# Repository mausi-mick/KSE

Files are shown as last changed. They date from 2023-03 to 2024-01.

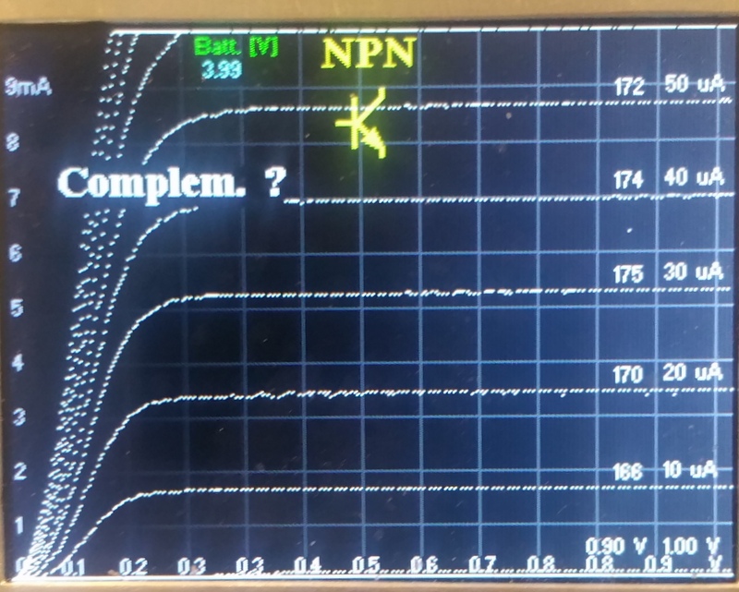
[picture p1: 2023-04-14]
SX1308_SDB628_Modul.jpg

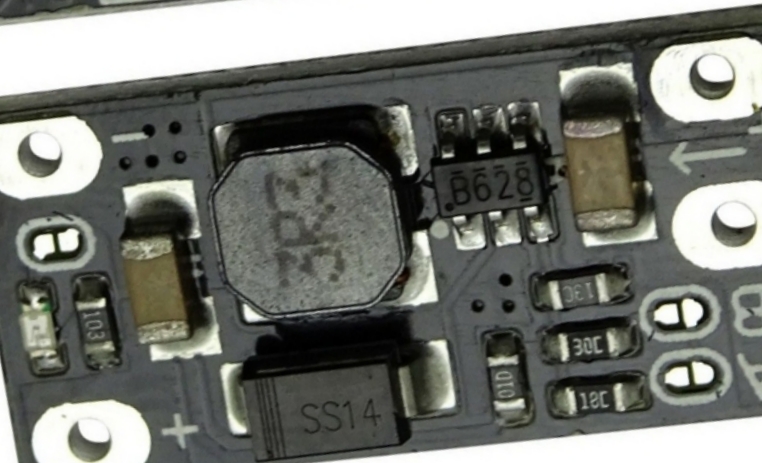
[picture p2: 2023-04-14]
SDB628.jpeg

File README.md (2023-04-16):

   Kleiner , feiner  Kennlinienschreiber

Wozu braucht man einen Kennlinienschreiber ?

Reicht nicht ein Transistortester oder ein Voltmeter?
Für einen ersten Check ist ein Transistortester sehr hilfreich, zumal er auch den Typ des Transistors  und die Pin-Belegung ermitteln und anzeigen kann.

Aber die Ausgabewerte beziehen sich dabei nur auf einen Arbeitspunkt (Kollektorstrom).
Für den Schaltungsentwickler ist es aber oft wichtig, wie sich das Bauteil an verschiedenen
Arbeitspunkten – z.B. Basisströmen – verhält.

Worin unterscheidet sich der hier vorgestellte Kennlineinschreiber von anderen?

    • kompakter Aufbau:                                                                                                 Abmessungen: 8x9x6cm (lxbxh),  Gewicht: < 500 g (inkl. 18650 Lio-Akku).
    • unabhängig von externer Stromversorgung (Akku Betrieb,mit einer 18650 Zelle)
    • ausgelegt für bipolar Transistoren/Dioden, MosFets, J-Fets(incl. Depl.Mode MosFets).
    • Kollektor/Emitterspannung < 12V , 0 ..150mA  optimal für Kleinleistungstransistoren
    • Basisstrom von ca 5µA ... 1000µA mit präziser Konstant-Stromquelle, 
    • Gatespannung  100 mV ...12 V in 100 mV Schritten (änderbar), 
    • einstellbare Strombegrenzung (z.B. Dioden 5mA, 50mA,…)
    • relativ grosses Farbdisplay (3.2“)
    • einfache und schnelle Eingabe über Dreh-Encoder an Interrupt-Pins
    • hohe Genauigkeit und klare Kennlinien dank 12 bit ADC’s / DAC’s
    • diverse Skalen für x (U) und y-(I) Achse : detaillierte Darstellung interessanter Bereiche
    • Direkter Vergleich von Kennlinien (Typen gleicher Polarität oder Komplementärtyp)
    • Anzeige von typischen Werten wie Beta(Ib), V-Threshold,V-Pinch, Idss
    • Bluetooth Schnittstelle (BLE 4.0) für Datentransfer zum PC bzw. Smartphone/ Tablet
    • Datentransfer über USB zur Darstellung der Kurven auf PC mit z.B. Processing.
    • Speichern der Eingabeparameter im internen EEPROM
    • geringer Stromverbrauch: Uce (15V) erst bei Messvorgang zugeschaltet. 
    • Zusatzfunktion: einstellbare  Konstantspannungsquelle 1 mV  bis 12, 00V,> 10 mA
    • Zusatzfunktion: einstellbare Konstanstromquelle von 1µA bis 4000 µA
    • Zusatzfunktion: Treppenstufengenerator für niedrige Frequenzen +4V, ...0V (...-4V) 
    • untergebracht auf 5 Platinen (Kicad) einlagig 
    • relativ niedrige Bauteilkosten

Dieser Kennlinienschreiber basiert auf dem sehr interessanten und gut dokumentierten Projekt von Peter Balch : Transistor Curve Tracer [1], aus dem auch u.a. die Grafik-library leicht modifiziert übernommen wurde.

Ich habe mich dann aber doch ziemlich  - auch vom Konzept her - weit davon entfernt, um eine bessere und rauschärmere Darstellung hinzubekommen mit einem deutlich erweiterten Messbereich ,einer einfachen Bedienung und erweiterter Funktionalität, was sich leider auch im Preis niederschlägt. 
Ich habe die bisherige Bedienung über das Touchpanel eliminiert und mache die Programmsteuerung und Parameteränderungen über zwei Drehencoder, die an den beiden ext. Interrupt-Pins des NANO hängen und so eine schnelle Reaktion ermöglichen. Die Eingabe ist hiermit – gerade bei dem kleinen Display und den vielen Parameterwerten – wesentlich angenehmer und schneller als per Touch. 

Der Nachbau ist wegen einiger SMDs  und der Verdrahtung einiger Platinen  komplexer und daher nicht unbedingt für „Anfänger“ geeignet. Bei einigen Spezial-ICs ist/war auch mit erheblichen Beschaffungszeiten (in Deutschland) zu rechnen.

Basis ist ein Arduino-NANO(Clone), am besten mit vorinstalliertem Opti-Boot Loader [2,3,4], da man dort 1.5 kB mehr freien Flash-Speicher hat, ansonsten hat man nur einige 100 Byte Flash frei.

Anmerkung:
 ATMega328 Board mit vorinstalliertem Opti-Boot-Loader: 
 z.B. Arduino-UNO, Adafruit Metro Mini 328,  oder ein Board mit mehr Flash und Port-Pins (für Erweiterungen): ATMega2560 ).

Anmerkung:
Auch das UNO-Board oder Adafruit Metro-Mini sind hier verwendbar, da ich die zusätzlichen rein analogen Pins des NANO (A6,A7) nicht benutze.

Das Adafruit-Board Metro Mini 328 hat neben der besseren Anordnung der Pins (alle digit.Pins und somit auch Pin13 (SPI-SCK)  auf einer Seite) auch die Möglichkeit, durch eine Lötbrücke die Pegel auf 3.3V zu setzen, sodass man für das Display und das HM-10 BLE-Modul keine Spannungsteiler zur Pegelanpassung benötigt.

Der Mikroprozessor steuert zwei 12bit-DACs (im MCP4822 SPI) für die Uce Versorgung , ausserdem für die Basis/Gate-Ansteuerung einen 12 bit DAC (MCP4725-I2C) an, der über einen DC/DC-Wandler (5 V → 30V) und für den I2C Bus über einen ADUM1250/51 isoliert betrieben wird.  

Dieser total isolierte DAC (Bereich von 1µA bis 4mA, 1µA Schritte, hier nur von 5µA bis 1200µA genutzt für die bipol. Transistoren genutzt) erzeugt den Basisstrom bzw. die Gate-Spannung in der – zum Bauteil / „device“ - passenden Polarität über eine Präzisionskonstantstromquelle.
 
Zugeschaltet wird der Basisstrom (bzw. die Gatespannung)  über elekronische Schalter („Photomos-Relais“) mit niedrigem On-Widerstand und Leckstrom (z.B. TLP222A ).

Neben diesen DACs wird auch ein 12-bit ADC (MCP3402 SPI) zur Messung der Collector-EmitterSpannung und zur am Messwiderstand RS (50 Ohm) abfallenden Spannung (zur Ermittlung des Collector-Stroms) verwandt. Er dient auch zur Überwachung der Akku-Spannung.
Momentan werden nur 3 von den 4 Eingängen des ADC’s genutzt.

Ausserdem versorgt der NANO das bis zu 3.2 Zoll grosse Farb-Display (ILI9341) (an SPI-Bus).

Probleme gab es mit den 4 SPI-Devices wegen der unterschiedlichen Geschwindigkeit, da das Display mit 8 MHz läuft, die DAC’s mit 3.6 MHz und der ADC aber nur mit 2 MHz                      (und der Touch noch langsamer, wird aber in dieser Version nicht genutzt).

Als realisierbare / nicht ganz perfekte Lösung speichere ich maximal 320-Messwerte pro eingestelltem Basisstrom in einer Tabelle mit SPI-Speed 2 MHz ab.
Anschliessend erhöhe ich die SPI-Speed auf 8MHz für das Display und
 gebe die Tabellenwerte auf dem Display aus, um dann wieder – mit reduzierter SPI-Speed - die nächsten 320 Messwerte zum nächsten Basisstrom zu speichern.

Die Spannung Uc wird über die beiden DACs des MCP4822 erzeugt, wobei DAC-B nur
die Werte (0V, 2V,4V ...10V) am Opamp TCA0372 ausgibt,
DAC-A erzeugt die Zwischenwerte von 0.0mV, 0.5mV, 1.0mV.,..2000mV.
Sie werden dann zu den aus DC-B erzeugten Werten addiert (zwei invertierende Verstärker hintereinandergeschaltet) , sodass insgesamt der Bereich von
0V bis 12V in 0.5mV – Schritten mit sehr guter Linearität erzeugt werden kann.
Diese Auflösung ist zwar etwas übertrieben, bei kleinen Spannungswerten (z.B. Kennlinie von Shottky-Dioden oder im Anfangsbereich der Kurven von bipolar bzw. Feldeffekttransistoren) bringt das aber was, auch wird durch eine Art „Oversampling“ der Mittelwert der Messungen zum gleichen x_Wert gebildet

Der Summierverstärker TCA0372 mit Verstärkung +1 für DAC_A und Verstärkung +10 für DAC_B ist in Abbildung 1 skizziert.
Da der TCA0372 kein Rail-to Rail Vertärker ist, benötigt er eine negative Hilfsspannung: 
 aus den +15V wird mithilfe eines kleinen Spannungswandlers (LMO78-5-.5 )  -5V erzeugt. 
Damit erhält man auch in Nullpunktsnähe saubere Kurven, gerade die 1, 2, 3V Skalen profitieren davon.

Stromversorgung

Versorgt wird der Kennlinienschreiber aus einer einzelnen Lion-Akku-Zelle (18650).
Es werden zwei Spannungen benötigt:
   5V für  Adafruit Metro mini bzw. 7,5V Arduino NANO) , an der auch das Diplay und die KonstantStromquelle hängen, und ca.
 15V zur Versorgung des TCA0372-Verstärkerboards (Uce).

Die zuerst untersuchte Lösung mit zwei MT3608 Modulen funktionierte stabil nur für die 15V Versorgung, bei der Microprocessorversorgung brach die Spannung bereits bei einer Akkuspannung von 3.9V ein.

Die Qualität der MT3608-Module  – neben der riskanten Inbetriebnahme (siehe unten) – ist aber sehr unterschiedlich, sodass ich auch eher andere Module verwenden würde.
Die ICs MT3608, SDB628 und SX1308 scheinen – auch vom Datenblatt – identisch zu sein.
Aber die Module haben unterschiedliches Layout und wohl auch unterschiedliche Bestückung.

Die Kondensatoren C1 C2 sollten 22µF haben, bei den von mir untersuchten Modulen lagen sie 
unter 10 µF.

Es funktioniert sehr gut mit einem kleinen SX1308-Modul, bei dem bei mir aber ein SDB628 StepUp-Wandler IC aufgelötet war. 

Das Modul ist ähnlich wie das MT3608-Modul aufgebaut, aber
niederohmiger: 
10 k anstelle 100k Trimmer und 200 Ohm gegen Masse anstelle 2.2k. [9]

Es ist bei 15V mit mehr als 150mA belastbar und funktioniert bereits ab ca 2.7 V.
Es ist auch für die 5V / 7,5V Vesrorgung sehr gut geeignet.

Für die 5 bzw. 7.5V verwende ich momentan ein kleines Modul mit festen Spannungswerten  (5V,8V,9V,12V). Es ist wohl ein SDB628 verbaut ( identisch mit MT3608 / SX1308?)  das Modul funktioniert sogar  bis unter 3V Eingansspannung. [10]

Anmerkung MT3608:
Etwas kritisch ist die Einstellung/Inbetriebnahme, da der Schleifer des 10-Gang-Trimmers direkt mit dem FB (Feedback-Pin 3)  verbunden ist und - am oberen Anschlag  -  die Ausgansspannung direkt mit FB  verbunden ist, der wohl nur 0.6V ? verträgt.
Man sollte also vor Anlegen der Eingansspannung den Regler mit ein einigen Umdrehungen aus der oberenAnschlagsposition bringen (und zwar nach höheren Ausgansspannungswerten , d.h. nach links drehen   chinesische Logik ??)   [5,6],

Um Energie zu sparen, wird die 15V Versorgung erst aktiviert, wenn die Kurven aufbereitet werden.
Die 7.5V / 5V  stehen nach Einschalten für das Microprocessor Board gleich zur Verfügung, an dem u.a.  das Display und die Konstanstromquelle hängen, die aber weniger als 1W benötigt.

Beim Einschalten sind die Ströme - auch wegen der Kondensatoren - deutlich höher.

Das Adafruit Board braucht wegen eines besseren LD-Reglers , auch reichen hier 5V am  herausgeführten USB-Eingang.
9],[10],[11]

Testen von Bauteilen

Nach diesem technischen Überblick mal etrwas mehr zum Test-Ablauf:

Nach dem Einschalten erscheint auf dem Display der Startbildschirm , auf dem an der linken Seite nur drei grosse Icons  aufleuchten mit Auswahlfeldern (Buttons) für:
    •  bipolar Transistoren (inclusive Dioden)
    •  Mosfets
    •  Junction-Fets (incl. n-Depletion-Mode-Mosfets)
      
die über einen Drehencoder angesteuert werden.
Die Aktivierung einer Schaltfläche erfolgt durch Drehen des 2. Encoders.
Daraufhin werden im oberen Bereich zwei Schaltflächen („P“ bzw „N“) zum Starten des Messvorgangs angezeigt, vorher sollte man aber die unterhalb in zwei Spalten dargestellten Parameter begutachten  und eventuell modifizieren.
Im mittleren Display Bereich an der linken Seite  die Parameter: 

    •  min:   minimaler Wert (Basisstrom bzw. Gatespannung), mit dem der Messvorgang gestartet werden soll
    •  incr: Schrittweite, mit der Basisstrom bzw. Gatespannung erhöht werden soll
    •  max:  maximal datzustellende  Basisstrom bzw. Gatespannungs-Kurve

Die Basisströme werden in µA eingetragen, die Gatespannung in 100mV Schritten.
 Von einer Diode wird dann ausgegangen, wenn bei  „bipolar“ das Feld  incr: auf 0 gesetzt wird.

Am rechten Rand des Displays werden folgende Parameter angezeigt:

    •   Bluet/CCS: Transfer der Daten mit BLE 4.0 an PC bzw Smartphone,  bzw.    Konstantspannungs-Konstantspannungs-Betrieb
    •   x-scale[V]:    Länge der x-Skala  ( 1V,  2V,  3V,  4V,  6V,  12V)
    •   y-scale[mA]  Höhe   der y-Skala ( 2 mA, 5 mA, 10 mA, 20 mA, 50 mA, 100 mA)
Anmerkung: 
 Feld Bluet/CCS = 0         Ausgabe der Kennliniendaten 
                            = 1        Ausgabe der Kennliniendaten auch über Bluetooth an Smartphone etc. 
                            = 2        Umschalten auf Konstantspannungsquellen-Betrieb
                            = 3        Umschalten auf  Konstantstromquellen-Betrieb   
                            = 4,5 ,6 Treppenstufengenerator. 
                            
Die Verwaltung der Parameter erfolgt ähnlich wie beim Startbildschirm beschrieben, zwischen den Feldern springt man durch Drehen des Encoders 2, Auswahl eines Paramters durch mit dem anderen Encoder, ändern der Parameter duch Encoder-Drehung, Speichern/Verlassen des Parameters durch den andren Encoder.

Ist man mit den Einstellungen zufrieden, startet man den Messvorgang / Kurven durch Positionieren mit dem  Encoder auf Feld „P“  (für p-Devices) bzw. “N“ (für n-Devices)  
Hier hat man eine geringe Wartezeit zum Aktivieren, in der man nochmals die Parameter prüfen sollte. In dieser Wartephase blinken die aktivierten Felder P  bzw N. Durch drehen des anderen Encoders startet man dann den Messvorgang.

Erst jetzt sieht man die ausgewählten Skalen und im oberen Bereich das ausgewählte Device inclusive Icon.

Die Kurven werden vom x-y-0-Punkt aufgebaut und zusätzliche Daten (wie z.B. beta/hfe beim npn/pnp und der Basisstrom/Gatespannung )  am Ende der Kurven eingetragen.

Am Ende der Messung bleibt der Bildschirm mit den dargestellten Kurve stehen und es erscheint links oben eine Anfrage / Aufforderung in zeitlichem Abstand :

    •   ob man die Messung beenden will  („Stop ?“)
    •   ob man die Messung fortsetzen will mit geänderten Parametern  („Param ?“)
    •   ob man das gerade dargestellte Bauteil mit einem Bauteil gleicher Polarität vergleichen will („Compare ?“) 
    •   ob man das gerade dargestellete Bauteil mit einem Bauteil anderer Polarität vergleichen will („Complem. ?“)  (komplementär-Typ z.B. antiparallele Diode)

Die Auswahl erfolgt wieder durch Encoderdrehung zu dem gerade angezeigten Aufforderung.

Anmerkung:

Will man z.B. die Kennlinien von einem n-Device mit einem p-Device vergleichen, ermittelt man zuerst normal die Kennlinien des n-Devices, tauscht das n gegen das p-Device in der Textool Messfassung und startet den Vergleich 
durch Auswahl des Feldes „Complementary“ mit dem Encoder .

Es werden die Kennlinien des p-Devices zusätzlich in einer anderen Farbe auf dem Display dargestellt („Komplementärtyp“).

Vergleich von Komponenten gleicher Polarität erfolgt entsprechend 
durch Auswahl des Feldes „Compare“.

   Speicherung geänderter Parameter-im internen EEPROM

Die festgelegten Parameter werden beim Start der Kurven im internen EEPROM hinterlegt , 
sodass man auch beim Einschalten des Geräts die letzt eingegebenen Parameter angezeigt bekommt. 

Im EEPROM sind dafür folgende Adressen belegt:

    •   0: Transistor-Typ  0: bipolar,
    •   1: Bluetooth : 1=on, 0=off
    •   2: x-Skala: 1,2,3,4,6,12
    •   3 y-Skala: 2,5,10,20,50,100 mA
    •   4: minimaler Basisstrom bipolar-Transistor
    •   6: maximaler Basisstrom bipolar-Transistor 
    •   8: increment Basisstrom bipolar-Transistor 
    • 10: minimale Stepweite für Eingabe  min: ( Feld 4 )
    • 12: minimale StepWeite für Eingabe max: ( Feld 6 )
    • 14: minimale StepWeite für Eingabe incr:: ( Feld 8 )

    •   20: Transistor-Typ  1:  Mosfet
    •   21: Bluetooth : 1=on, 0=off
    •   22: x-Skala: 1,2,3,4,6,12
    •   23 y-Skala: 2,5,10,20,50,100 mA
    •   24: minimaler Gatespannung Mosfet
    •   26: maximaler GatespannungMosfet 
    •   28: increment Gatespannung Mosfet 
    •   30: minimale Stepweite für Eingabe  min: ( Feld 24 )
    •   32: minimale StepWeite für Eingabe max: ( Feld 26 )
    •   34: minimale StepWeite für Eingabe incr:: ( Feld 28 )

    •   40: Transistor-Typ  2:  J-Fet 
    •   41: Bluetooth : 1=on, 0=off
    •   42: x-Skala: 1,2,3,4,6,12
    •   43 y-Skala: 2,5,10,20,50,100 mA
    •   44: minimaler  Gatespannung J-Fet
    •   46: maximaler Gatespannung-J-Fet 
    •   48: increment  Gatespannung J-Fet 
    •   50: minimale Stepweite für Eingabe  min: ( Feld 44 )
    •   52: minimale StepWeite für Eingabe max: ( Feld 46 )
    •   54: minimale StepWeite für Eingabe incr:: ( Feld 48 )

Ausserdem kann man den Bauteil-Namen (z.B. BC548C  oder auch andere Informationen) im internen EEProm ab Adresse 100/101 hinterlegen: 

    •   100: Länge des Textfeldes 
    •   101: Text 1. Byte
    •   102: Text 2. Byte
    •  ...
 das Textfeld wird im Display unterhalb der P / N Buttons angezeigt und ist über einen Encoder basierten kleinen Editor verwaltbar – maximal 11 Einträge.
: 
   
 Datentransfer  über Bluetooth (BLE 4.0)

In das Gerät ist ein HM-10 Module integriert mit BLE 4.0, es ist über .Wippschalter mit der seriellen Schniitstelle RX / TX und damit mit USB verbunden. 
Die Aktivierung des Transfers erfolgt im Auswahl-Menü rechts oben unterhalb „N“-Button.
Bluet./CCS:  1   (0 für  Blutetooth nicht aktiviert)
Folgende Werte werden mit Separator Linefeed (“\n“ ) übertragen:

    • X:  x Skala und nachflolgend 1,2,3,4,6 oder 12 die SpannungsEndwerte der x-Achse
    • Y:  y-Skala und nachfolgend 2,5,10,20,50,100 die StromEndwerte der y-Achse
    • P  bzw. N : die Polarität (npn/pnp,nMos,pMos,nJFet,pJFet)
    • T, M, F (D) : der Typ (Transistor(bipolar), Mosfet, jFet (Diode noch nicht real.)
    • C: Kurve pro Basisstrom bzw. Gatespannung     hier werden jetzt bis zu 320 Werte der y- Achse  - durch Komma getrennt  -  ausgegeben
    • Q: Ende der Kurve
    • B:  bzw. G : für Basisstrom bzw. Gatespannung
    • E : Error Fehlermeldung bei Überschreitung des maximalen Collector-Stroms
    • H : hfe/beta von bipolar-Transistoren in Abhängigkeit vom Basisstrom (am Ende der Kurve)
    • O: Ohm (bei j_Fet mit Skala 1V ermittelt bei Uds =0.5V)
    • D : Diodenstrom bei Ud in mA (Diode wird „erkannt“, wenn bei npn/pnp incr=0)
    • U : Diodenspannung Ud bei Idiode in mV (Fluss bzw. Sperrspannung bei Zener < 12V)
    • Z : Ende der Kurve

Anmerkung  Bei ausgeschaltetem HM-010 Modul (BLE 4.0) können in Stellung  Bluet./CCS = 1
obige Parameter über USB an den PC übertragen werden und z.B. mit TeraTerm überwacht werden.

Verwendung als präzise KonstantSpannungsquelle

Der Modus:  Konstantspannungsquelle wird mit  Bluet./CCS = 2  aktiviert :

hier kann man bei dem Parameter  min.incr und max:  den den Spannungswert
bis maximal 12 V angeben. 

Verwendung als präzise Konstantstromquelle

Der Modus:  Konstantstromquelle wird mit  Bluet./CCS = 3  aktiviert :

hier kann man bei dem Parameter  max:  den den Konstanstrom in µA (1...4000) angeben. 

Verwendung als Treppenstufengenerator

Der Modus:  Treppenstufengenerator wird mit  Bluet./CCS  >= 4  aktiviert :

    • 4:  nur Stromwerte steigen von min::  µA bis max:  µA mit Schrittweite incr: µA
    • 5:  Stromwerte steigen (wie bei   4: ) und fallen 
    • 6:  Stromwerte steigen und fallen wie bei 5 :  mit Umschaltung Strom in negative Richtung (Treppenkurven von  maximal +4V … 0   -4V )
Die Verweildauer pro Stufe in µs wird über die Parameter x-scale und y-scale festgelegt.

Die Frequenz ergibt sich aus der Verweildauer und der über die Parameter-
 min:,  incr:  max:  festgelegten Stufenanzahl.

   Erweiterungsmöglichkleiten / Ausblick

    • grösserer Spannungs- / Strombereich Uce/Ic
Für manche Anwendungen ist der Spannungsbereich (Uce <= 12V)-
 bzw. Strombereich ( <100mA ) nicht ausreichend.
  Ein Betrieb mit bis zu 24V (der DC/DC-Wandler liefert maximal 28V) ist ohne HW-Änderungen möglich, allerdings zu Lasten des Stromverbrauchs , da sollte man das Gerät auf Betrieb mit 2 oder mehr Lion-Zellen umbauen oder den NANO mit 3.3V/3.6V betreiben (Umbauanleitungen im Netz, ab 3.6 V sicherer Betrieb des ATMega328P mit 20 MHz ). Da geht dann der Stromverbrauch im standby drastisch runter und man spart sich die Pegelanpassung für das TFT-Display. Ich hab aber die SPI-Schnittstellen zu den DACs und ADCs (auf dem TC0372-Board) bei 3.6V nicht getestet.
  Ein höherer Strombereich ist kritischer, da dann u.a. auch der Schaltregler an seine Grenzen kommt und der TCA0372 gekühlt werden müsste.

    • grösserer Strom Konstantstromquelle / CCS
   bis ca 10 mA leicht durch Ersetzen des Messwiderstandes  (250 Ohm) der CCS auf z.B 100 Ohm.
   Oberhalb muss man wohl u.a. auch den DC/DC-Wandler (1W/30V) wechseln und das Platinenlayout und den Mosfet entsprechend anpassen.

    • Schnittstelle zum Transistortester( „TT“):

            automatische Erkennung des Bauteils inclusive Pin-Zuordnung. 
Das ist mit dem NANO mit der jetzt integrierten Funktionalität nicht möglich, da der Flashspeicher bereits zu 99% belegt ist. Man müsste dann auf einen anderen Microprozessor zurückgreifen, z.B. den ATMega2560, der dazu auch noch eine Menge Port-Pins zur Verfügung stellt. 
Ich hab das mal – in einer einfacheren Version – mit einem NANO (+ Portexpander MCP23017 )  realisiert  [7],[8] : 
-   Erweiterung TT um serielle Schnittstelle( SoftwareSerial) und Übertragen
         Transistortyp/Polarität,Belegung Pin1,2,3 ...
  - Verlegung (Duplizierung)  der Textool-Pins des TT s in eine 3x3-Matrix Schaltbox,
 -  Einbau Serielle Schnittstelle in Kennlinienschreiber zum Lesen der Daten vom TT .
 -.. Starten Kennlineinschreiber mit den Steuerungs-/Schalt-Daten vom TT .
Das hat damals – mit erheblichen Schaltungsaufwand – gut funktioniert.

    • Speichern auf SD-Karte 
  Speichern auf SD-Karte ist nur mit „grösserem“ Prozessor (ATMega2560) siehe oben möglich,
  da die Bibliotheken viel Platz benötigen .

   Hardware-Komponenten

hier sind jetzt nur die wesenlichen Komponenten / Module aufgeführt, die Details kann man den KiCad Stücklisten entnehmen.

    • ILI9341 SPI-Display (3.2“) (Touch Version nicht nötig)
    • Arduino NANO bzw. Clone (möglichst mit OptiBoot-Bootloader)
    • MCPM4822 Dual-DAC 12 bit SPI
    • MCP3204-Quad-ADC 12 bit SPI
    • MCP4725DAC 12 bit I2C
    • ADuM1250/1 ISOLATOR I2C 
    • DC/DC RH0515 1W 5V to 30V 
    • TCA0372 Dual Power Amplifier
    • LMO78-05.05  +7..+24V to – 5V
    • Textool Fassung
    • Dreh-Encoder (2 Stück)
    • 10 x PhotoMosrelais (z.B. TLP222A)  
    • 2 x SX1308 Module s ( 3 V..4.2V --> 7,5V bzw. --->15 V)
    • Lion-Akku incl. Halterung
    • Lademodul Lion-Akku
    • HM-10 Module Bluetooth 4.0

      für diese Komponenten hab ich etwa  80  € ausgegeben, momentan ist aber mit höheren
      Preisen zu rechnen.

[1] https://www.instructables.com/Transistor-Curve-Tracer/
[2] GitHub - Optiboot/optiboot: Small and Fast Bootloader for Arduino and other Atmel AVR chips 
[3]  Neusten Bootloader flashen auf Arduino Nano China clone – Thing King – Technik & DIY (thing-king.de)
[4] How do I install optiboot on the newest arduino IDE? - Using Arduino / Programming Questions - Arduino Forum 

[5] https://chips-and-more.com/cm/pdf/K3608.pdf
[6] https://datasheetspdf.com/pdf-file/909246/AEROSEMI/MT3608/1
[7] https://www.youtube.com/watch?v=7WQflcy4CrQ
[8] https://www.youtube.com/watch?v=ybFWR0rq9jg
[9] https://www.ebay.de/itm/234763127214?_trkparms=amclksrc%3
[10} https://www.ebay.de/itm/374349976165?hash=item5728ff5265
[11] https://www.ebay.de/itm/374349976165?            //  Step-UP SDB628  Modul ebay  3V to 5V
[12] https://pdf1.alldatasheet.com/datasheet-pdf/view/1132508/SHOUDING/SDB628.html   
                                                            // Step-UP SDB628  Datasheet

       Vergleich n-JFet BF256B mit p-JFet J176 Skala 6V 10mA
[13] https://www.youtube.com/shorts/95HiBvJB_0A
       NPN Skala: 2V, 5mA Parameter über Dreh-Encoder
[14] https://www.youtube.com/shorts/zspOeL5-aKM
       Kennlinienschreiber mit Präzisionskonstantstromquelle
[151] https://www.youtube.com/watch?v=6bx0Xuingm4
       Vergleich n-JFet BF256B mit p-JFet J176 Skala 1V 5mA
[16] https://www.youtube.com/shorts/LGOkdHCgLTI
        npn Test mit incr. 2,4,10,20 µA, Skala 4V 5mA
[17] https://www.youtube.com/watch?v=azDgB1QcklA&t=22s
       NPN Basistrom 5µA ... 240µA
[18] https://www.youtube.com/shorts/C6GhPL9V9Fg
      Kennlinienschreiber als bipolare Konstanstromqelle : Bereich 0 µA ... +/-1 mA
[19] https://www.youtube.com/watch?v=UbXDh1cYR88
      Kennlinienschreiber mit variablen Treppenstufengenerator
[20] https://www.youtube.com/watch?v=DciN_z7VIQE
      Kennlinienschreiber: Vergleich npn BC548 mit pnp BC558
[21] https://www.youtube.com/watch?v=N3BHx4Dii8s

Kalle Rüßmann

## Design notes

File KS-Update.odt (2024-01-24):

Kennlinienschreiber Udate (24.01.24)

Seit ich die Unterlagen für den „FUNK AMATEUR“ (März 2023) -

zusammengetragen habe, hat sich doch einiges getan:

zusätzlich zu den beiden Boards:

Arduino-NANO (mit OPTI-Boot 8.0) und dem

Adafruit Metro-Mini 328

hab ich noch andere Prozessoren getestet:

...Arduino EVERY (Prozessor ATmega4809), Board-layout wie NANO

...Raspberry PI Pico RP2040

…ESP32

Das Problem bei den beiden oberen Boards (mit ATMega328P) war die mangelnde Erweiterungsfähigkeit, da der Speicher (Flash) zu 99% voll war und alle Pins (bis auf die beiden rein anlogen A6/A7) belegt waren.

Ausserdem hat der ATmega328 nur 2 ext Interrupt Pins (wenn man von PCI (PinChangeInterrupt) absieht.

Der EVERY schien da etwas mehr zu bieten:

---mehr Flash: 48k (gegenüber 32k)

---mehr RAM 6k (gegenüber 2k)

–-mehr Speed 20Mhz (gegenüber 16 MHz)

---analogPin A6/A7 auch als digitalPin nutzbar

–-(fast) alle Pins interruptfähig

–-ähnliche Prozessorarchitektur und somit gleiche libs ? vewendbar

Beim letzten Punkt hab ich mich leider geirrt, viele hardware-nah programmierte libs

machten Ärger, gerade bei den grafic-libs (mit SPI), wo viel mit Registern etc gearbeitet wird.

Es war für mich (ich bin da leider nicht so firm) viel Arbeit, das umzustellen.

Es hat sich aber gelohnt:

Durch die 2 zusätzlichen digital-Pins und die interrupt-Fähigkeit hab ich einen zusätzlchen Taster

integrieren können und die 48k erlaubten die Integration einer SD-Karte (zum speichern der Kurven).

Tests mit dem Raspberry PICO RP2040 scheiterten, da ich die beiden Dreh-Encoder mit Interrupt

nicht stabil zum Laufen bekam.

Die Tests mit dem ESP32 Entwicklungsboard sehen bisher gut aus, ich hab aber hier den analogen Teil

(Strom-/Spannungsquelle für Ib bzw Vgate) und var. Spannungsquelle für Ic/Uce noch nicht getestet.

Dafür hat man es hier leichter mit Bluetooth BLE ( bei den anderenn Boards hab ich ein HM010 Bluetooth-Modul verwandt).

In Arbeit hab ich auch noch eine Version mit integrieretm Transistortester (TT), die (hoffentlich) auf dem NANO-Board läuft.

Der Messablauf sieht dann so aus:

Man steckt das zu testende Bauteil (DUT) in eine dreipolige Fassung, der TT ermittelt die Bauteildaten (npn/pnp,Mosfet,jFet,…) und die Pin-Zuordnung (z.B. Pin1=E,Pin2=B,Pin3=C ) und gibt diese Daten an den Kennlienschreiber weiter. Über eine 3x3 Schaltmatrix wird das Bauteil dann „richtig“ versorgt und die

Kurven auf dem Display dargestellt.

Der Kennlinienschreiber ist dann etwas rudimentärer (ähnlich wie in der Version von peter Balch),

Die Bedienung (eigentlich nur die Parameterwerte für die Skalen und BasisStrom/Gatespannung) erfolgt aber wohl über (einen) Encoder und einen Taster.

Hier benötige ich zusätzlich für die Schaltmatrix einen Portexpander.

Einfacher wäre das vermutlich mit einem ATMega5260/1280-board, da kann man sich den Expander

wohl sparen.

Hier noch eine Anmerkung zur Entwicklungsumgebung:

Ich hab die Arduino-Version 1.8.13 verwandt,

die KiCad Dateien sid zum grossen Teil mit Version 6.0 generiert, einige auch mit der 7.0.

Die Graphiken (Blockschaltbilder) sind zum grossen Teil mit der Freeware draw.io erstellt.

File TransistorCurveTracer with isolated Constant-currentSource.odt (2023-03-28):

.Small, fine TransistoCurveTracer

Why do you need a TransistorCurveTracer („TCT)“ ?

Isn't a transistor tester or a voltmeter enough?

A transistor tester is very helpful for a first check, especially because it can also determine and display the type of transistor and the pin assignment.

t.

But the output values only refer to one operating point (collector current).

For the circuit developer, however, it is often important how the component reacts to different

working points - e.g. base currents - behaves.

What is the difference between the TCT presented here and others?

• Compact construction: dimensions: 8x9x6cm , weight: < 500 g (incl. 18650 Lio battery).

• independent of external power supply (battery operation, with a 18650 cell)

• Designed for bipolar transistors/diodes, MosFets, J-Fets(incl. Depl.Mode MosFets).

• Collector/Emitter voltage < 12V, 0 ..150mA optimal for small power transistors

• Base current of approx. 5µA ... 1000µA with a precise constant current source,

• Gate voltage 100 mV ...12 V in 100 mV steps (changeable),

• Adjustable current limitation (e.g. diodes 5mA, 50mA,...)

• relatively large color display (3.2")

• easy to use and fast input via rotary encoders on interrupt pins

• high accuracy and clear characteristics thanks to 12 bit ADC's / DAC's

• Various scales for x (U) and y-(I) axis: detailed display of interesting areas

• Direct comparison of characteristics (types of the same polarity or complementary type)

• Display of typical values such as Beta(Ib), V-Threshold,V-Pinch, Idss

• Bluetooth interface (BLE 4.0) for data transfer to the PC or smartphone/tablet

• Data transfer via USB to display the curves on a PC with e.g. „Processing“.

• The input parameters are saved in the internal EEPROM

• Low power consumption: Uce (15V) only switched on during measurement.

• Additional function: adjustable constant voltage source 1 mV to 12.00V, > 10 mA

• Additional function: adjustable constant current source from 1µA to 4000 µA

• Additional function: Step generator for low frequencies +4V, ...0V (...-4V)

• housed on 5 boards (Kicad) with one layer

• relatively low component costs

This TCT is based on the very interesting and well-documented project by Peter Balch: Transistor Curve Tracer [1], from which the graphics library, among other things, was taken over in a slightly modified form.

But then I moved quite far away from it - also in terms of concept - in order to get a better and lower-noise display with a significantly extended measuring range, simple operation and extended functionality, which unfortunately is also reflected in the price.

I have eliminated the previous operation via the touch panel and do the program control and parameter changes via two rotary encoders that are connected to the two external NANO's interrupt pins, allowing quick response. The input is much more pleasant and faster than by touch, especially with the small display and the many parameter values.

The replica is more complex because of some SMDs and the wiring of some boards and therefore not necessarily suitable for "beginners". Considerable procurement times (in Germany) are/was to be expected for some special ICs.

The basis is an Arduino-NANO(clone), preferably with a pre-installed Opti-Boot Loader [2,3,4], because there you have 1.5 kB more free flash memory, otherwise you only some 100 bytes of free flash memory.

(ATMega328 board with pre-installed Opti-Boot-Loader: e.g. Arduino-UNO,Adafruit Metro Mini 328, or a board with more flash and port pins (for extensions): ATMega2560 ).

(Annotation:

The UNO board or Adafruit Metro-Mini can also be used here, since I don't use the additional purely analog pins of the NANO (A6,A7).

The Adafruit board Metro Mini 328 not only has the better arrangement of the pins (all digit.pins and thus also pin13 (SPI-SCK) on one side) but also the possibility of setting the level to 3.3V with a solder bridge, so that the display and the HM-10 BLE module do not require a voltage divider for level adjustment.

The microprocessor controls two 12-bit DACs (in the MCP4822 SPI) for the Uce supply, as well as a 12-bit DAC (MCP4725-I2C) for the base/gate control, which is connected via a DC/DC converter (5 V → 30V) and is operated isolated for the I2C bus via an ADUM1250.

This totally isolated DAC (range from 1µA to 4mA, 1µA steps, used here only from 5µA to 1200µA for the bipolar transistors) generates the base current or the gate voltage in the polarity that matches the component / "device".

The base current (or the gate voltage) is switched on via an electronic switch (“Photomos relay”) with a low on-resistance and leakage curren( e.g. TLP222A).

In addition to these DACs, a 12-bit ADC (MCP3402 SPI) is also used to measure the collector-emitter voltage and the voltage drop across the measuring resistor RS (50 ohms) (to determine the collector current). It is also used to monitor the battery voltage. Currently only 3 of the 4 inputs of the ADC are used.

In addition, the NANO supplies the up to 3.2-inch color display (ILI9341) (on SPI bus).

There were some problems with the 3/4 SPI devices because of the different speeds, since the display runs at 8 MHz, the DACs at 3.6 MHz and the ADC but only at 2 MHz (and the touch is even slower, but is not used in this version) . As a feasible / not quite perfect solution, I save a maximum of 320 measured values per set base current in a table with an SPI speed of 2 MHz. Then I increase the SPI speed to 8MHz for the display and output the table values on the display, in order to then save the next 320 measured values for the next base current - with reduced SPI speed. The voltage Uc is generated across the two DACs of the MCP4822, with DAC-B only outputs the values (0V, 2V,4V ...10V) at the opamp TCA0372, DAC-A generates the intermediate values of 0.0mV, 0.5mV, 1.0mV...2000mV. They are then added to the values generated from DC-B (two inverting amplifiers cascaded), so overall the range of 0V to 12V in 0.5mV steps can be generated with very good linearity.

This resolution is a bit exaggerated, but with small voltage values (e.g. characteristic curve of Shottky diodes or in the initial area of the curves of bipolar or field effect transistors) it is useful, and the mean value of the measurements for the same x_value is also formed through "oversampling".

The TCA0372 summing amplifier with gain +1 for DAC_A and gain +10 for DAC_B is sketched in Figure 1. Since the TCA0372 is not a rail-to-rail amplifier, it needs a negative auxiliary voltage: -5V is generated from the +15V using a small voltage converter (LMO78-5-.5). With this you get clean curves even near the zero point, especially the 1, 2, 3V scales benefit from it.

Power supply

The TCT is supplied by a single Lion battery cell (18650), the voltage for the NANO board (7.5 V) is generated with a step-up converter (MT3608). A second MT3608 is used to supply the TCA0372 amplifier board with 15V. The MT3608 has the advantage that it works from about 2.5V (important, since there is only one Lion cell is used (approx. 3V .... 4.2V). In addition, it works at around 1.2 MHz, so that there is little interference at the low frequencies.

Its setting/commissioning is somewhat critical, since the wiper of the 10-speed trimmer is connected directly to the FB (feedback pin 3) and at the upper stop the output voltage is connected directly to FB, which is probably only 0.6V? tolerates. So, before applying the input voltage, you should bring the controller a few turns from the upper stop position (namely after higher output voltage values, i.e. turn to the left Chinese logic ??) [5,6],

To save energy, the 15V supply is only activated when the curves are processed. After switching on, the 7.5V are immediately available for the microprocessor board, which includes the display and the constant current source, which, however, requires less than 1W. The NANO Board, including the display, requires approx. 400 mA during operation, but more than 1 A when switched on. The Adafruit board needs significantly less at 3.3V because of a better regulator, and about 6V at the input is also sufficient here.

After this technical overview, a little more about the test procedure:

After switching on, the start screen appears on the display, on which only three large icons appear on the left side with selection fields (buttons) for:

•

bipolar transistors (including diodes) •

Mosfets •

J-Fets (incl. n depletion mode mosfets)

which are controlled via a rotary encoders. A button is activated by turning the 2nd encoder. Two buttons ("P" or "N") for starting the measurement process are then displayed in the upper area.

Before doing so, however, you should examine and possibly modify the parameters displayed in two columns below. The parameters in the middle of the display:

• min: minimum value (base current or gate voltage) with which the measurement process is to be started

• incr: Increment with which the base current or gate voltage is to be increased

• max: maximum base current or gate voltage curve to be displayed

The base currents are entered in µA, the gate voltage in 100mV steps.

A diode is assumed if the field incr: is set to 0 for "bipolar".

The following parameters are shown on the left edge of the display:

• Bluet/CCS: Transfer of data with BLE 4.0 to PC or smartphone, or constant current/constant voltage operation

• x-scale[V]: length of the x-scale ( 1V, 2V, 3V, 4V, 6V, 12V)

• y-scale[mA] height of the y-scale ( 2 mA, 5 mA, 10 mA, 20 mA, 50 mA, 100 mA)

Annotation:

Field Bluet/CCS = 1 Output of characteristic curve data to smartphone via Bluetooth

= 2,...6 switching to constant voltage source, constant current source or stair step generator.

The management of the parameters is similar to that described for the start screen, you jump between the fields by turning encoder 2, selecting a parameter with the other encoder 1, changing the parameter by turning the encoder, saving/exiting the parameter with encoder 2. If you are satisfied with the settings, start the measurement process / curves by turning the other encoder: "P" (for p-devices) or "N" (for n-devices) r Here you have a short waiting time to activate, in which you should check the parameters again. During this waiting phase, the activated fields P and N flash. Only now do you see the selected scales and the selected device including icon in the upper area. The curves are built up from the x-0 point and additional data (such as beta/hfe for npn/pnp and the base current/gate voltage) are entered at the end of the curves. At the end of the measurement, the screen with the displayed curve stops and a query / request appears at the top left,

• whether you want to end the measurement ("Stop ?")

• whether you want to continue the measurement with changed parameters ("Param ?")

• whether you want to compare the currently displayed component with a component of the same polarity ("Compare ?")

• whether you want to compare the currently displayed component with a component of a different polarity (“Complem. ?”) (complementary type, e.g. anti-parallel diode)

Annotation:

For example, if you want to compare the characteristics of an n-device with a p-device, you first determine the characteristics of the n-device normally, exchange the n for the p-device in the text tool measurement version and start the comparison by selecting the field "Complementary “ with encoder and activation with button. The characteristics of the p-device are immediately shown in a different color on the display ("complementary type"). Components of the same polarity are compared by selecting the "Compare" field.

Storage of changed parameters in the internal EEPROM

The specified parameters are stored in the internal EEPROM when the curves are started, so that the last parameters entered are displayed when the device is switched on. The following addresses are assigned in the EEPROM:

• 0: transistor type 0: bipolar,

• 1: Bluetooth : 1=on, 0=off

• 2: x-scale: 1,2,3,4,6,12

• 3 y scale: 2.5,10,20,50,100mA

• 4: minimum base current bipolar transistor

• 6: maximum base current bipolar transistor

• 8: increment base current bipolar transistor

• 10: minimum step size for input min: (field 4)

• 12: minimum step width for input max: (field 6)

• 14: minimum step width for input incr:: ( field 8 )

• 20: Transistor Type 1: Mosfet

• 21: Bluetooth : 1=on, 0=off

• 22: x-scale: 1,2,3,4,6,12

• 23 y scale: 2.5,10,20,50,100mA

• 24: minimum gate voltage Mosfet

• 26: maximum gate voltage Mosfet

• 28: increment gate voltage Mosfet

• 30: minimum step width for input min: (field 24)

• 32: minimum step width for input max: (field 26)

• 34: minimum step width for input incr:: ( field 28 )

• 40: Transistor Type 2: J-Fet

• 41: Bluetooth : 1=on, 0=off

• 42: x-scale: 1,2,3,4,6,12

• 43 y scale: 2.5,10,20,50,100mA

• 44: minimum gate voltage J-Fet

• 46: maximum gate voltage-J-Fet

• 48: increment gate voltage J-Fet

• 50: minimum step size for input min: (field 44)

• 52: minimum step width for input max: (field 46)

• 54: minimum step width for input incr:: ( field 48 )

You can also store the device name (e.g. BC548C or other information) in the internal EEProm from address 60:

• 60: length of the text field

• 62 text 1st byte

• 63 text 2nd byte • ..

. the text field / device-name is shown in the display below the P / N buttons and can be managed via a small encoder-based editor - a maximum of 11 entries. :

Data transfer via Bluetooth (BLE 4.0)

An HM-10 module with BLE 4.0 is integrated into the device, it is connected to the

serial interface RX / TX and thus to USB via a rocker switch.

The transfer is activated in the selection menu

at the top right below the "N" button. Bluet./CCS: 1 (0 for Bluetooth not activated

the following values are transmitted with Separator Linefeed (“\n“ ):

• X: x scale and then 1,2,3,4,6 or 12 the voltage end values of the x-axis

• Y: y-scale and then 2,5,10,20,50,100 the current end values of the y-axis

• P or N : the polarity (npn/pnp,nMos,pMos,nJFet,pJFet)

• T, M, F (D) : the type (transistor(bipolar), mosfet, jFet (diode not real yet.)

• C: Curve per base current or gate voltage Here, up to 320 values of the y-axis - separated by commas - are output

• Q: end of curve • (not activated)

• B: or G : for base current or gate voltage

• E : Error Error message when the maximum collector current is exceeded

• H : hfe/beta of bipolar transistors as a function of base current (at the end of the curve)

• O: Ohm (at j_Fet with scale 1V determined at Uds =0.5V)

• D : diode current at Ud in mA (diode is "recognized" if at npn/pnp incr=0)

• U : diode voltage Ud at Idiode in mV (flux or blocking voltage at Zener < 12V)

• Z : end of curve

Note When the HM-010 module (BLE 4.0) is switched off, in the position Bluet./CCS = 1

The above parameters can be transferred to the PC via USB and monitored with TeraTerm, for example.

Use as a precise constant voltage source

The mode: constant voltage source is activated with Bluet./CCS = 2:

here you can use the parameters min.incr and max: the voltage value specify up to a maximum of 12 V.

Use as a precise constant current source

The mode: constant current source is activated with Bluet./CCS = 3: Here you can enter the constant current in µA (1...4000) in the max: parameter.

Use as a stair step generator

The mode: staircase generator is activated with Bluet./CCS >= 4:

• 4: only current values increase from min: µA to max: µA with increment incr: µA

• 5: current values rise and fall as in 4:

• 6: Current values rise and fall as with 4: with current switching in the negative direction (staircase curves from a maximum of +4V … 0 -4V )

The dwell time per level in µs is defined via the parameters x-scale and y-scale.

The frequency results from the length of stay and the parameter min:, incr: max: specified number of steps.

Expansion options / outlook

• larger voltage / current range Uce/Ic

For some applications the voltage range (Uce <= 12V)- or current range (<100mA) not sufficient. Operation with up to 24V (the DC/DC converter delivers a maximum of 28V) is possible without hardware changes, but at the expense of power consumption, the device should be converted to operate with 2 or more Lion cells or the NANO with 3.3 Operate V/3.6V (conversion instructions in the network, from 3.6 V safe operation of the ATMega328P with 20 MHz). Then the power consumption in standby drops drastically and you save yourself the level adjustment for the TFT display. I haven't tested the SPI interfaces to the DACs and ADCs (on the TC0372 board) at 3.6V though. A higher current range is more critical, since then, among other things, the switching regulator will also reach its limits and the TCA0372 would have to be cooled.

• larger current constant current source / CCS

up to approx. 10 mA easily by replacing the measuring resistor (250 ohms) of the CCS to e.g. 100 ohms. Above that you probably have to change the DC/DC converter (1W/30V) and adjust the board layout and the mosfet accordingly.

• Interface to the transit site tester (“TT”):

automatic recognition of the component including pin assignment.

This is not possible with the NANO with the now integrated functionality, since the flash memory is already 99% occupied. You would then have to use another microprocessor, e.g. the ATMega2560, which also provides a large number of port pins.

I did it - in a simpler version - with a NANO (+ port expander MCP23017 ) [7],[8] :

- Extension TT to serial interface (SoftwareSerial) and transfer Transistor type/polarity, assignment pin1,2,3 …

- Transfer (duplication) of the textool pins of the TT in a 3x3 matrix switch box,

- Installation of a serial interface in the characteristic curve recorder for reading the data from the TT.

-.. Start the characteristic curve recorder with the control/switching data from the TT. That worked well at the time – with a considerable amount of circuitry.

• Save to SD card

Saving on an SD card is only possible with a "larger" processor (ATMega2560) see above, since the libraries require a lot of space.

• Hardware components

only the essential components / modules are listed here, the details can be found in the KiCad parts lists.

• ILI9341 SPI display (3.2") (touch version not required)

• Arduino NANO or clone (if possible with OptiBoot bootloader)

• MCPM4822 dual DAC 12 bit SPI

• MCP3204 Quad ADC 12 bit SPI

• MCP4725DAC 12bit I2C

• ADuM1250/1 ISOLATOR I2C

• DC/DC RH0515 1W 5V to

• TCA0372 Dual Power Amplifier

• LMO78-05.05 +7..+24V to – 5V

• Textool version

• Rotary encoder (2 pieces)

• 10 x PhotoMos relays (e.g. TLP222A) •

• 2 x MT3608 boards (3 V..4.2V --> 7.5V or --->15 V)

• Lion battery incl. holder

• Lion battery charging module

• HM-10 modules Bluetooth 4.0

I spent about 80 € for these components, but at the moment it is with higher ones prices to be expected.

[1] https://www.instructables.com/Transistor-Curve-Tracer/

[2] GitHub - Optiboot/optiboot: Small and Fast Bootloader for Arduino and other Atmel AVR chips (https://github.com/Optiboot/optiboot)

[3] Neusten Bootloader flashen auf Arduino Nano China clone – Thing King – Technik & DIY (thing-king.de) (https://www.thing-king.de/arduino-nano-neusten-bootloader-flashen-auf-arduino-nano-china-clone/)

[4] How do I install optiboot on the newest arduino IDE? - Using Arduino / Programming Questions - Arduino Forum (https://forum.arduino.cc/t/how-do-i-install-optiboot-on-the-newest-arduino-ide/345443)

[5] https://chips-and-more.com/cm/pdf/K3608.pdf

[6] https://datasheetspdf.com/pdf-file/909246/AEROSEMI/MT3608/1

[7] https://www.youtube.com/watch?v=7WQflcy4CrQ

[8] https://www.youtube.com/watch?v=ybFWR0rq9jg

Vergleich n-JFet BF256B mit p-JFet J176 Skala 6V 10mA

[9] https://www.youtube.com/shorts/95HiBvJB_0A

NPN Skala: 2V, 5mA Parameter über Dreh-Encoder
[10] https://www.youtube.com/shorts/zspOeL5-aKM

Kennlinienschreiber mit Präzisionskonstantstromquelle

[11] https://www.youtube.com/watch?v=6bx0Xuingm4

Vergleich n-JFet BF256B mit p-JFet J176 Skala 1V 5mA
[12] https://www.youtube.com/shorts/LGOkdHCgLTI

npn Test mit incr. 2,4,10,20 µA, Skala 4V 5mA
[13] https://www.youtube.com/watch?v=azDgB1QcklA&t=22s

NPN Basistrom 5µA ... 240µA

[14] https://www.youtube.com/shorts/C6GhPL9V9Fg

Kennlinienschreiber als bipolare Konstanstromqelle : Bereich 0 µA ... +/-1 mA
[15] https://www.youtube.com/watch?v=UbXDh1cYR88

Kennlinienschreiber mit variablen Treppenstufengenerator

[16] https://www.youtube.com/watch?v=DciN_z7VIQE

Kennlinienschreiber: Vergleich npn BC548 mit pnp BC558

[17] https://www.youtube.com/watch?v=N3BHx4Dii8s

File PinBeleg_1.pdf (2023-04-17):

Connection NANO to other PCB's

Seite 1

Board | NANO | NANO | CCS | CVS | Divider | Power-MT3608
Pin NANO | | PortName | Function | Pin Name Source
| Connector | | | | Conn_CCS | | Conn_CVS | | 5V to 3.3V | | SW15V_Ubat?
D1 / TX | | PD1 | USB / BLE4
D0 / RX | | PD0 | USB / BLE4
Reset | | PC6
Gnd | | | Power | | J1-1/J2-4 | Gnd | J1/J2-Pin1 | Gnd | J1-2/J-10 | Gnd | J2-1
D2 | | PD2 | ISR | pin_ENC2_A
D3 | | PD3 | ISR | pin_ENC1_A
D4 | | PD4 | GPIO | pin_ENC1_B
D5 | | PD5 | GPIO | pin_ENC2_B
D6 | | PD6 | GPIO | pin_ADC_CS | | | J1-Pin2
D7 | | PB7 | GPIO | pin_DAC_CS | | | J1-Pin3
D8 | | PB0 | GPIO | not used
D9 | | PB1 | GPIO | TFT_CS | | | | | J1-3 | R_CS_G1
D10 | | PB2 | GPIO | TFT_DC | | | | | J1-4 | R_DC1
D11 | | PB3 | SPI MOSI | SPI_MOSI | | | J1-Pin5 | | J1-5 | R_MOSI1
D12 | | PB4 | SPI MISO | SPI_MISO | | | J1-Pin6 | | J1-6 | R_MISO1
D13 | | PB5 | SPI SCK | SPI_SCK | | | J1-Pin4 | | J1-7 | R_SCK1
A0 / D14 | | PC0 | GPIO | pin_E_NEG | | | J4-Pin2 | N-devices | | | J2_1
A1 / D15 | | PC1 | GPIO | pin_E_POS | | | J4-Pin3 | P-devices | | | J2_2
A2 / D16 | | PC2 | GPIO | pin_CV_SW | J2-3
A3 / D17 | | PC3 | GPIO | pin_EB | J2-2 | P-devices
A4 / D18 | | PC4 | I2C SDA | I2C_SDA | J1-2
A5 / D19 | | PC5 | I2C SCL | I2C_SCL | J1-3
A6 | | ADC[6] | only analog | not used | | | | | | | J2-3
A7 | | ADC[7] | only analog | not used
+5V | | | | | J1-2 | +5V | | | J1-1 | +5V
Reset | | PC6
Gnd | | | Power
Vin | | 6.7-12V | Power

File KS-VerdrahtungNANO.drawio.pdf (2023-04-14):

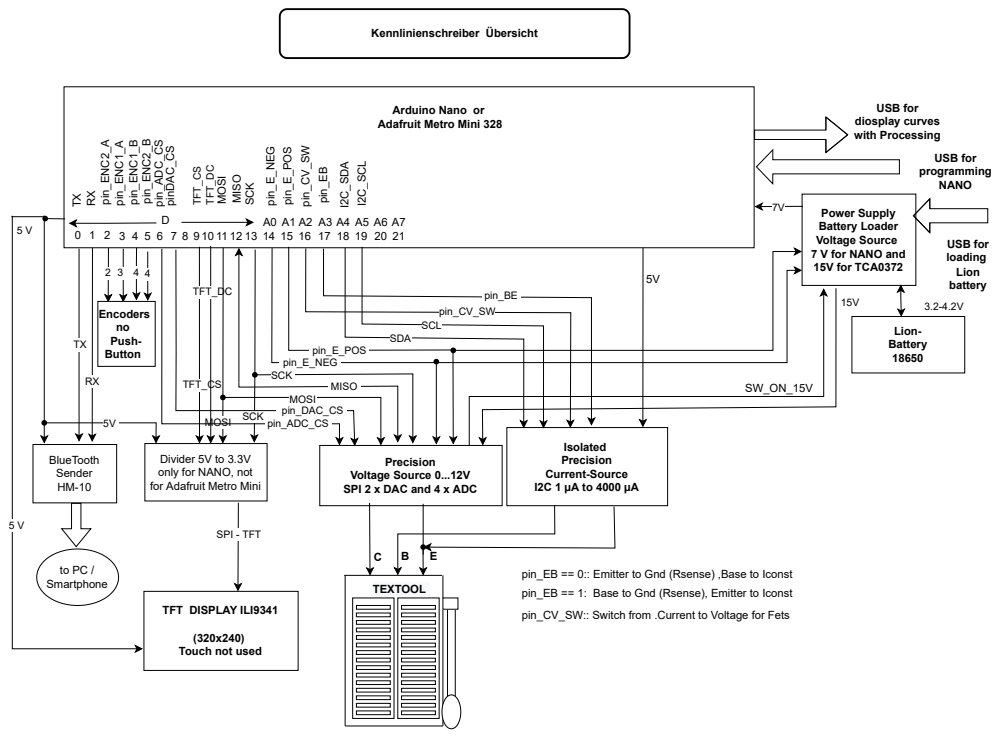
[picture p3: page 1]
Kennlinienschreiber Übersicht; TFT DISPLAY ILI9341; to PC / Smartphone; USB for loading Lion battery; SPI - TFT; BlueTooth Sender HM-10; TXd; MOSI SCK; SDA; SCL; pin_CV_SW; pin_BE; pin_ADC_CS; pin_DAC_CS; TFT_CS; TFT_DC TFT_CS TFT_DC; pin_ADC_CS pinDAC_CS; MOSI; MISO; SCK; pin_E_NEG; pin_E_POS; Lion- Battery 18650; TEXTOOL; USB for programming NANO; Encoders no Push- Button; pin_ENC2_A; pin_ENC1_B; pin_EB; I2C_SDA; I2C_SCL; pin_ENC1_A; pin_ENC2_B; USB for diosplay curves with Processing

Arduino Nano or
Adafruit Metro Mini 328

Power Supply
Battery Loader
Voltage Source
7 V for NANO and
15V for TCA0372

Isolated
Precision
Current-Source

Divider 5V to 3.3V
only for NANO, not
for Adafruit Metro Mini

Voltage Source 0...12V
SPI 2 x DAC and 4 x ADC

pin_EB == 0:: Emitter to Gnd (Rsense) ,Base to Iconst
pin_EB == 1: Base to Gnd (Rsense), Emitter to Iconst
pin_CV_SW:: Switch from .Current to Voltage for Fets

Touch not used

USB for
loading
18650

Switch from const.Current(I) to const.Voltage(U) for Fets

P_EB: Base to Gnds, Emitter to Iconst

P_BE: Emitter to Gnds, Base to Iconst

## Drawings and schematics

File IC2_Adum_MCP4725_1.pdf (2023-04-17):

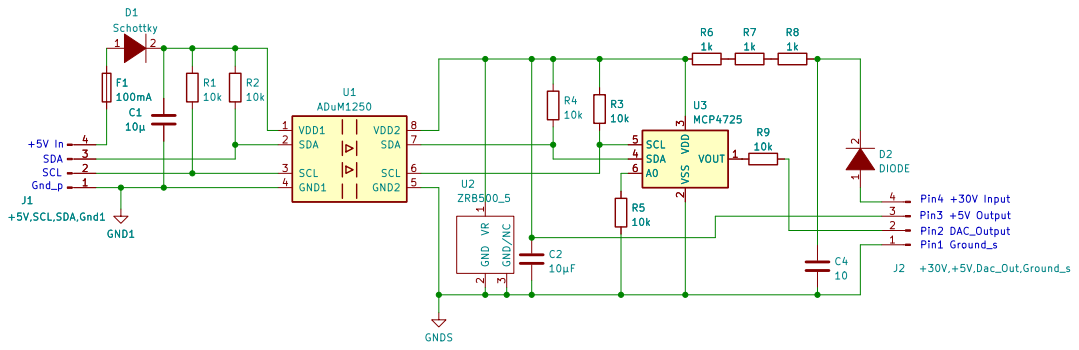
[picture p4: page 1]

3 U2 ZRB500_5 VDD1 1 SDA 2 SCL 3 GND1 4 GND2 5 SCL 6 SDA 7 VDD2 8 U1 ADuM1250 GNDS

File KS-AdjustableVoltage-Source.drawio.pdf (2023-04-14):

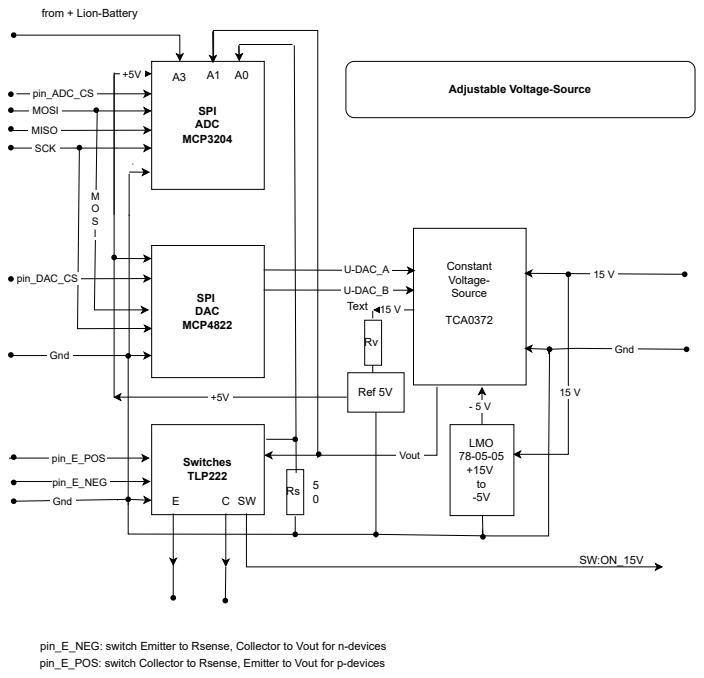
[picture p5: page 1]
Constant Voltage- Source; TCA0372; Ref 5V; SPI ADC MCP3204; MOSI; MISO; SCK; SPI DAC MCP4822; Switches TLP222; Gnd; pin_E_NEG; U-DAC_A; U-DAC_B; pin_E_POS; pin_ADC_CS; pin_DAC_CS; Vout; LMO 78-05-05 +15V to -5V; Text

from + Lion-Battery

Adjustable Voltage-Source

pin_E_NEG: switch Emitter to Rsense, Collector to Vout for n-devices
pin_E_POS: switch Collector to Rsense, Emitter to Vout for p-devices

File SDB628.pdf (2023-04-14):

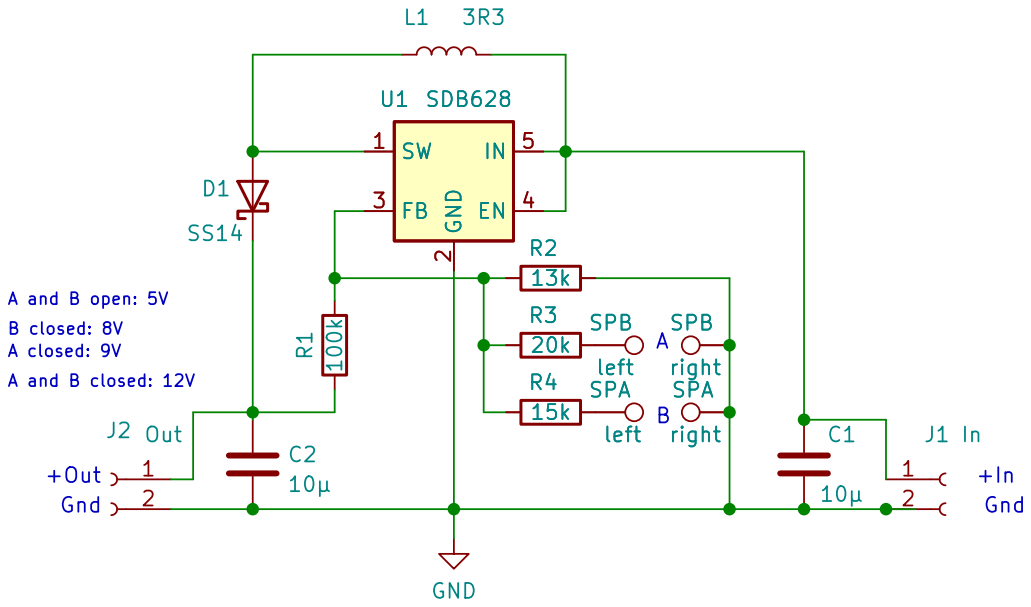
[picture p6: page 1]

Id: 1/1 Title: SDB628-Modul-Schematic

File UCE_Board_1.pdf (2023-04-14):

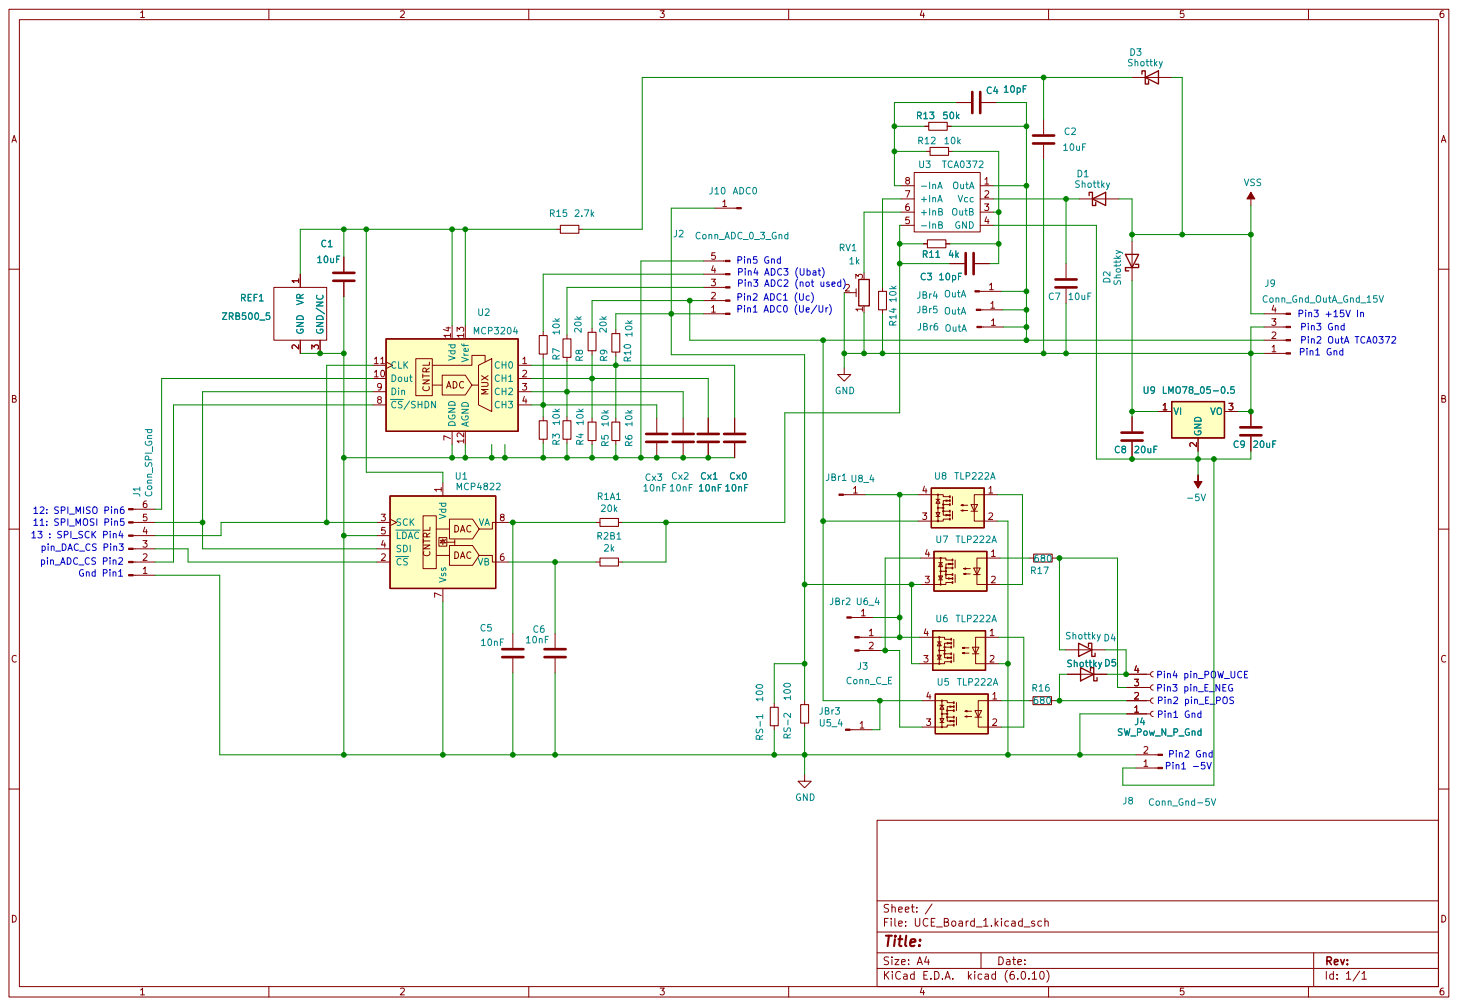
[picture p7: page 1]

1 ~{CS} 2 SCK 3 SDI 4 ~{LDAC} 5 VB 6 Vss 7 VA 8 U1MCP4822 R9 20k ADC CNTRL MUX CH0 1 Dout 10 CLK 11 AGND 12 Vref 13 Vdd 14 CH1 2 CH2 3 CH3 4 DGND

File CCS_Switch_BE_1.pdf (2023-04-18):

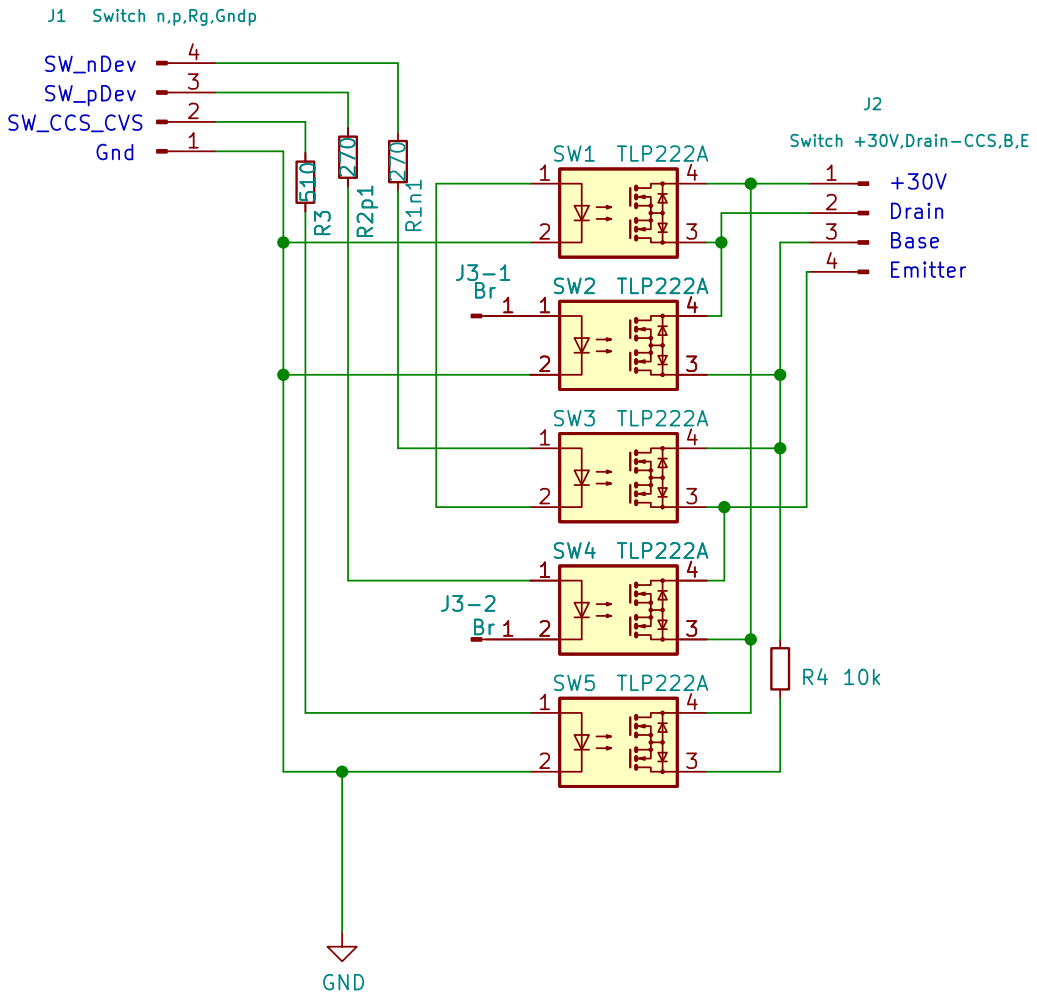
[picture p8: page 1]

4 SW4 TLP222A

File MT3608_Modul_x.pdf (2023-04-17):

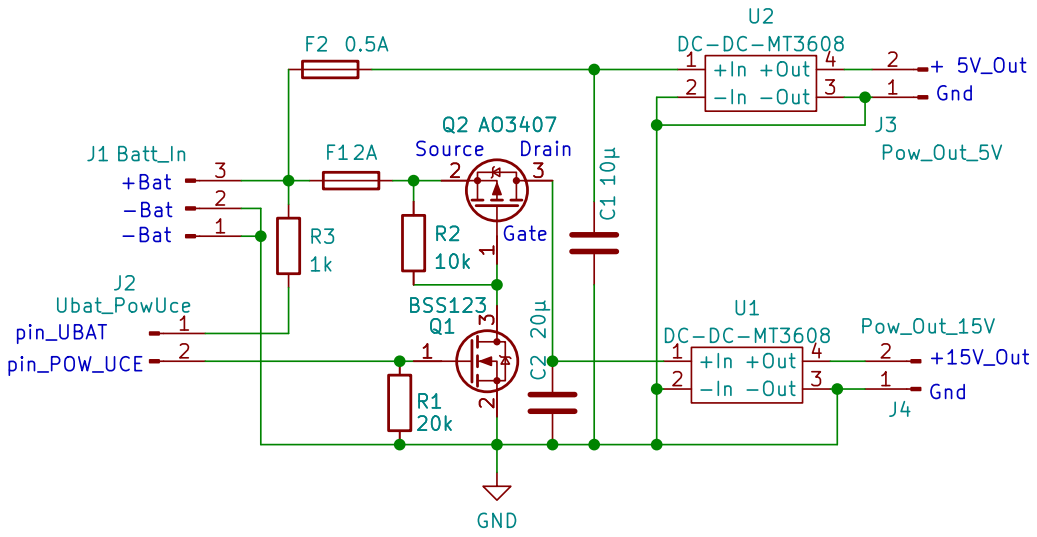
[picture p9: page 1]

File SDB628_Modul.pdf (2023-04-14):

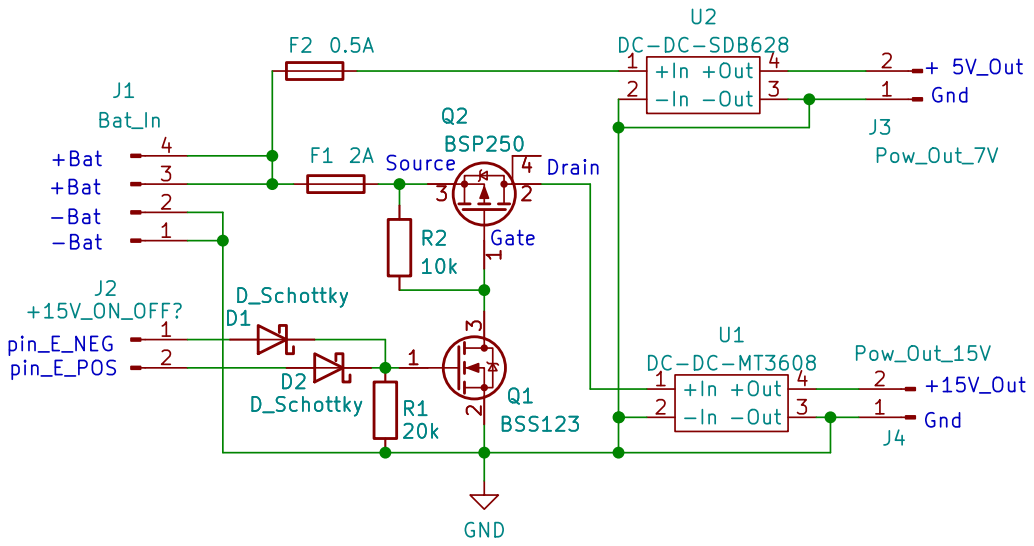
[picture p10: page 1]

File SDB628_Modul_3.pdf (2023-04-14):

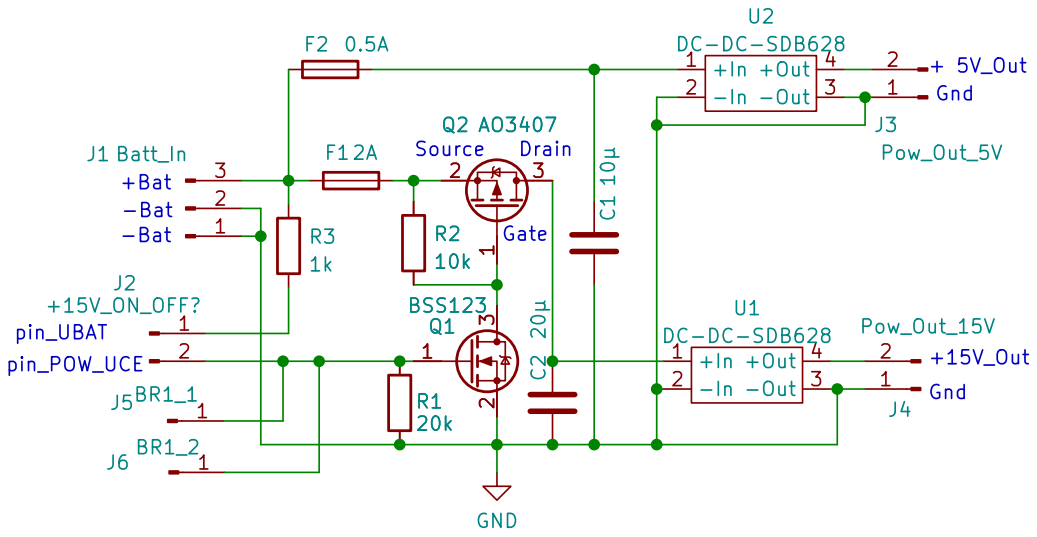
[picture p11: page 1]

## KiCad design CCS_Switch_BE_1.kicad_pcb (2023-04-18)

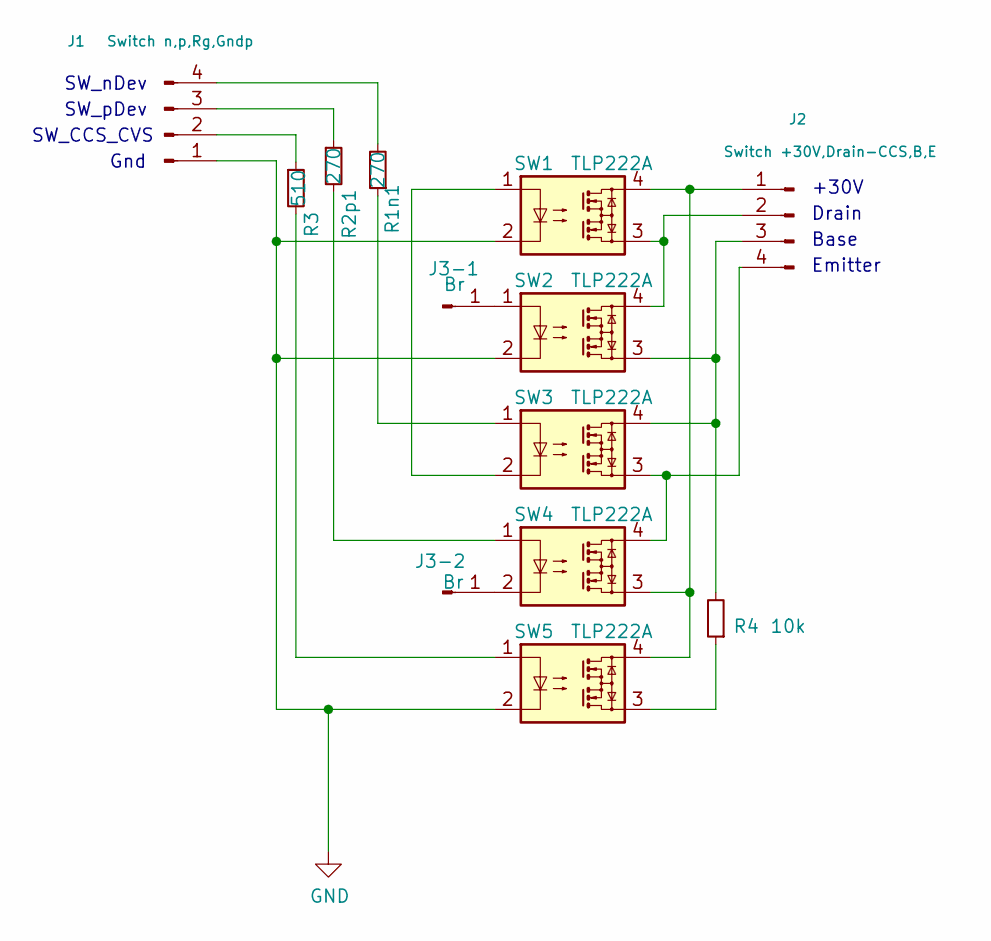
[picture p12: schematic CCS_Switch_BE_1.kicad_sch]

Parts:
J1: Switch n,p,Rg,Gndp; PinHeader_1x04_P2.54mm_Vertical
J2: Switch +30V,Drain-CCS,B,E; PinHeader_1x04_P2.54mm_Vertical
J3-1, J3-2: Br; PinHeader_1x01_P2.54mm_Vertical
R1n1, R2p1: 270; R_1206_3216Metric_Pad1.30x1.75mm_HandSolder
R3: 510; R_1206_3216Metric_Pad1.30x1.75mm_HandSolder
R4: 10k; R_Axial_DIN0207_L6.3mm_D2.5mm_P10.16mm_Horizontal
SW1, SW2, SW3, SW4, SW5: TLP222A; DIP-4_W7.62mm

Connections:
GND: J1.1, SW1.2, SW2.2, SW5.2
unnamed: J1.2, R3.1
unnamed: J1.3, R2p1.1
unnamed: J1.4, R1n1.2
unnamed: J2.1, SW1.4, SW4.3, SW5.4
unnamed: J2.2, SW1.3, SW2.4
unnamed: J2.3, R4.2, SW2.3, SW3.4
unnamed: J2.4, SW3.3, SW4.4
unnamed: J3-1.1, SW2.1
unnamed: J3-2.1, SW4.2
unnamed: R1n1.1, SW3.1
unnamed: R2p1.2, SW4.1
unnamed: R3.2, SW5.1
unnamed: R4.1, SW5.3
unnamed: SW1.1, SW3.2

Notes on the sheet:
Base
SW_pDev
SW_CCS_CVS
SW_nDev
+30V
Drain
Emitter
Gnd

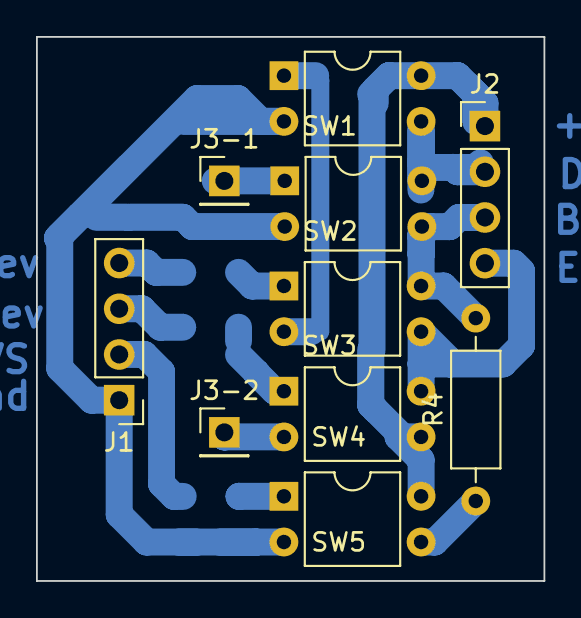
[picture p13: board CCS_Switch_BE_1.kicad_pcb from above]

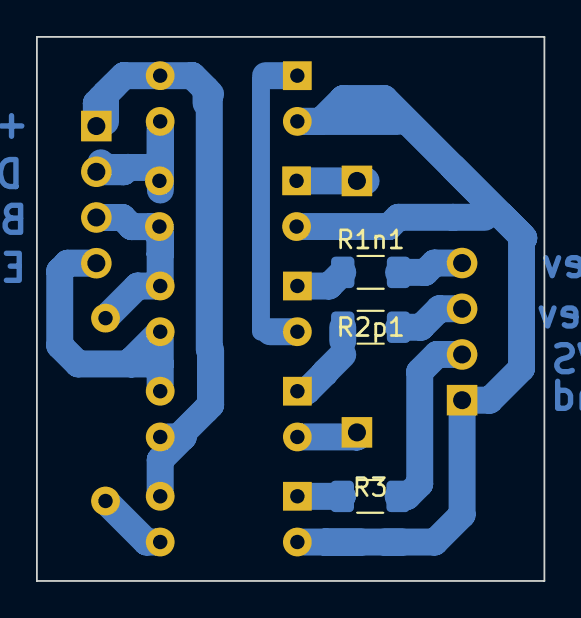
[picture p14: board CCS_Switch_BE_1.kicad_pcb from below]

Board: 2 copper layers, 28.2 x 30.2 mm, 13 parts (3 on the bottom side), 15 nets.

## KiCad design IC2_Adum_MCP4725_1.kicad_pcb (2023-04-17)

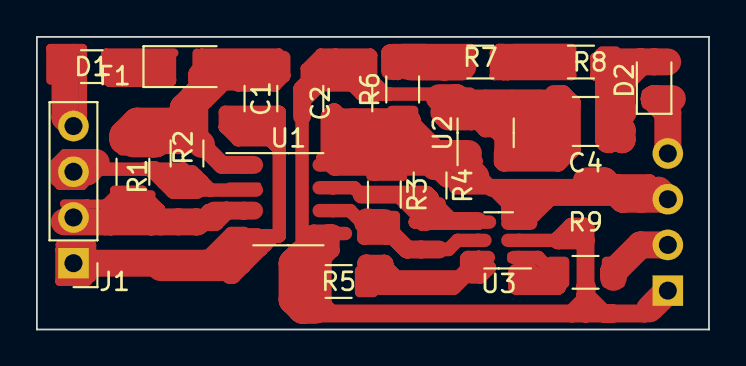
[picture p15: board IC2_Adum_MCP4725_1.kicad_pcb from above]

Board: 2 copper layers, 37.3 x 16.3 mm, 20 parts (1 on the bottom side), 17 nets.

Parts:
C1: 10µ; C_1206_3216Metric_Pad1.33x1.80mm_HandSolder
C2: 10µF; C_1210_3225Metric_Pad1.33x2.70mm_HandSolder
C4: 10; C_1210_3225Metric_Pad1.33x2.70mm_HandSolder
D1: Schottky; D_1206_3216Metric_Pad1.42x1.75mm_HandSolder
D2: DIODE; D_0805_2012Metric_Pad1.15x1.40mm_HandSolder
F1: 100mA; Fuse_1206_3216Metric_Pad1.42x1.75mm_HandSolder
J1: +5V,SCL,SDA,Gnd1; PinHeader_1x04_P2.54mm_Vertical
J2: +30V,+5V,Dac_Out,Ground_s; PinHeader_1x04_P2.54mm_Vertical
R1, R2, R3, R4, R5, R9: 10k; R_1206_3216Metric_Pad1.30x1.75mm_HandSolder
R6, R7, R8: 1k; R_1206_3216Metric_Pad1.30x1.75mm_HandSolder
U1: ADuM1250; SOIC-8_3.9x4.9mm_P1.27mm
U2: ZRB500_5; SOT-23-3
U3: MCP4725; SOT-23-6

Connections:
GND1: C1.2, J1.1, U1.4 (GND1)
GNDS: C2.2, C4.2, J2.1, R5.2, U1.5 (GND2), U2.2 (GND), U2.3 (GND/NC), U3.2 (VSS)
unnamed: C1.1, D1.2 (A), R1.1, R2.1, U1.1 (VDD1)
unnamed: C2.1, J2.3, R3.1, R4.1, R6.1, U1.8 (VDD2), U2.1 (VR), U3.3 (VDD)
unnamed: C4.1, D2.2 (A), R8.2
unnamed: D1.1 (K), F1.1
unnamed: D2.1 (K), J2.4
unnamed: F1.2, J1.4
unnamed: J1.2, R1.2, U1.3 (SCL)
unnamed: J1.3, R2.2, U1.2 (SDA)
unnamed: J2.2, R9.2
unnamed: R3.2, U1.6 (SCL), U3.5 (SCL)
unnamed: R4.2, U1.7 (SDA), U3.4 (SDA)
unnamed: R5.1, U3.6 (A0)
unnamed: R6.2, R7.1
unnamed: R7.2, R8.1
unnamed: R9.1, U3.1 (VOUT)

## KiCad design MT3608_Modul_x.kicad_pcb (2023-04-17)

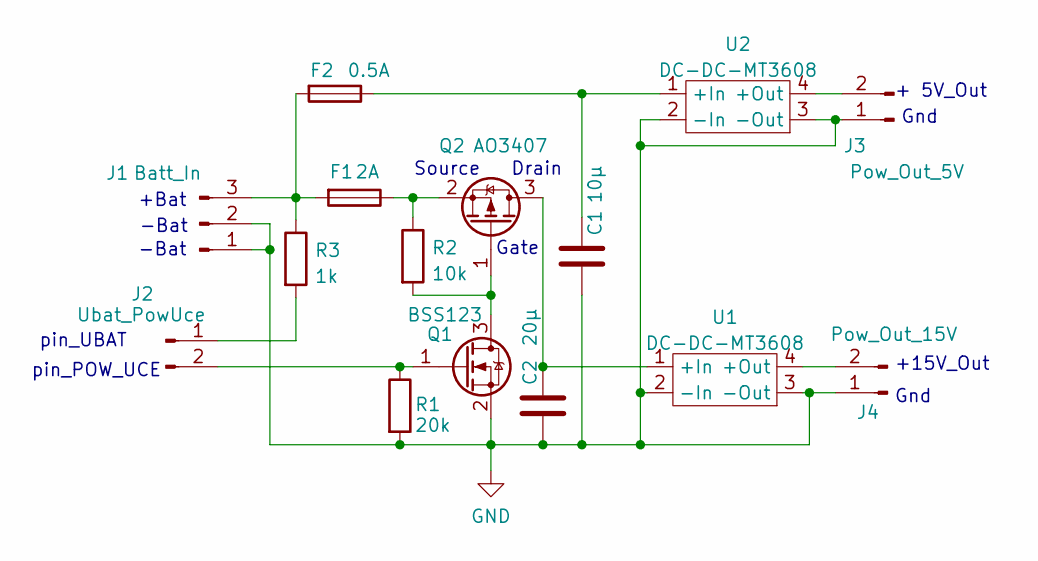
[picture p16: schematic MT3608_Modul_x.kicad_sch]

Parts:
C1: 10µ; C_1206_3216Metric_Pad1.33x1.80mm_HandSolder
C2: 20µ; C_1210_3225Metric_Pad1.33x2.70mm_HandSolder
F1: 2A; Fuse_1206_3216Metric_Pad1.42x1.75mm_HandSolder
F2: 0.5A; Fuse_1206_3216Metric_Pad1.42x1.75mm_HandSolder
J1: Batt_In; PinHeader_1x03_P2.54mm_Horizontal
J2: Ubat_PowUce; PinHeader_1x02_P2.54mm_Vertical
J3: Pow_Out_5V; PinHeader_1x02_P2.54mm_Vertical
J4: Pow_Out_15V; PinHeader_1x02_P2.54mm_Vertical
Q1: BSS123; SOT-23
Q2: AO3407; SOT-23
R1: 20k; R_1206_3216Metric_Pad1.30x1.75mm_HandSolder
R2: 10k; R_1206_3216Metric_Pad1.30x1.75mm_HandSolder
R3: 1k; R_1206_3216Metric_Pad1.30x1.75mm_HandSolder
U1, U2: DC-DC-MT3608

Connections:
GND: C1.2, C2.2, J1.1, J1.2, J3.1, J4.1, Q1.2 (S), R1.2, U1.2 (-In), U1.3 (-Out), U2.2 (-In), U2.3 (-Out)
unnamed: C1.1, F2.1, U2.1 (+In)
unnamed: C2.1, Q2.3 (D), U1.1 (+In)
unnamed: F1.1, Q2.2 (S), R2.1
unnamed: F1.2, F2.2, J1.3, R3.1
unnamed: J2.1, R3.2
unnamed: J2.2, Q1.1 (G), R1.1
unnamed: J3.2, U2.4 (+Out)
unnamed: J4.2, U1.4 (+Out)
unnamed: Q1.3 (D), Q2.1 (G), R2.2

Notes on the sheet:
Drain
pin_UBAT
-Bat
Source
+Bat
pin_POW_UCE
+15V_Out
Gnd
Gate
+ 5V_Out

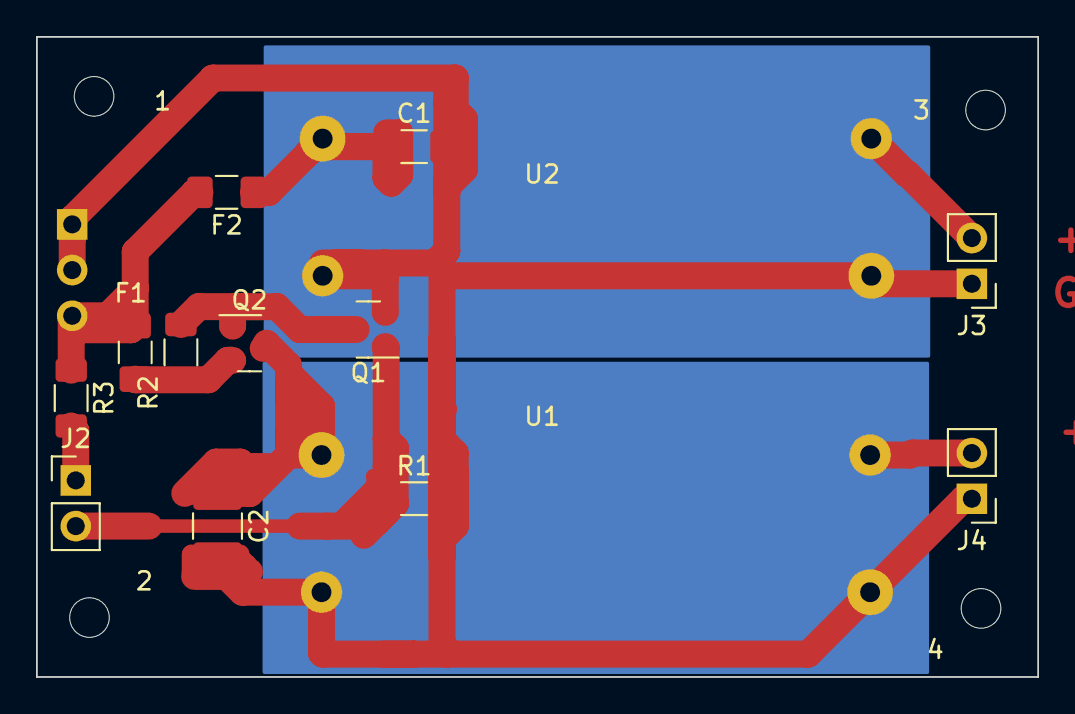
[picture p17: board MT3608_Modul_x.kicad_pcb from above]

Board: 2 copper layers, 55.6 x 35.6 mm, 19 parts (1 on the bottom side), 10 nets.

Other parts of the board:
1, 2, 3, 4: MH_M2; MountingHole_2.2mm_M2

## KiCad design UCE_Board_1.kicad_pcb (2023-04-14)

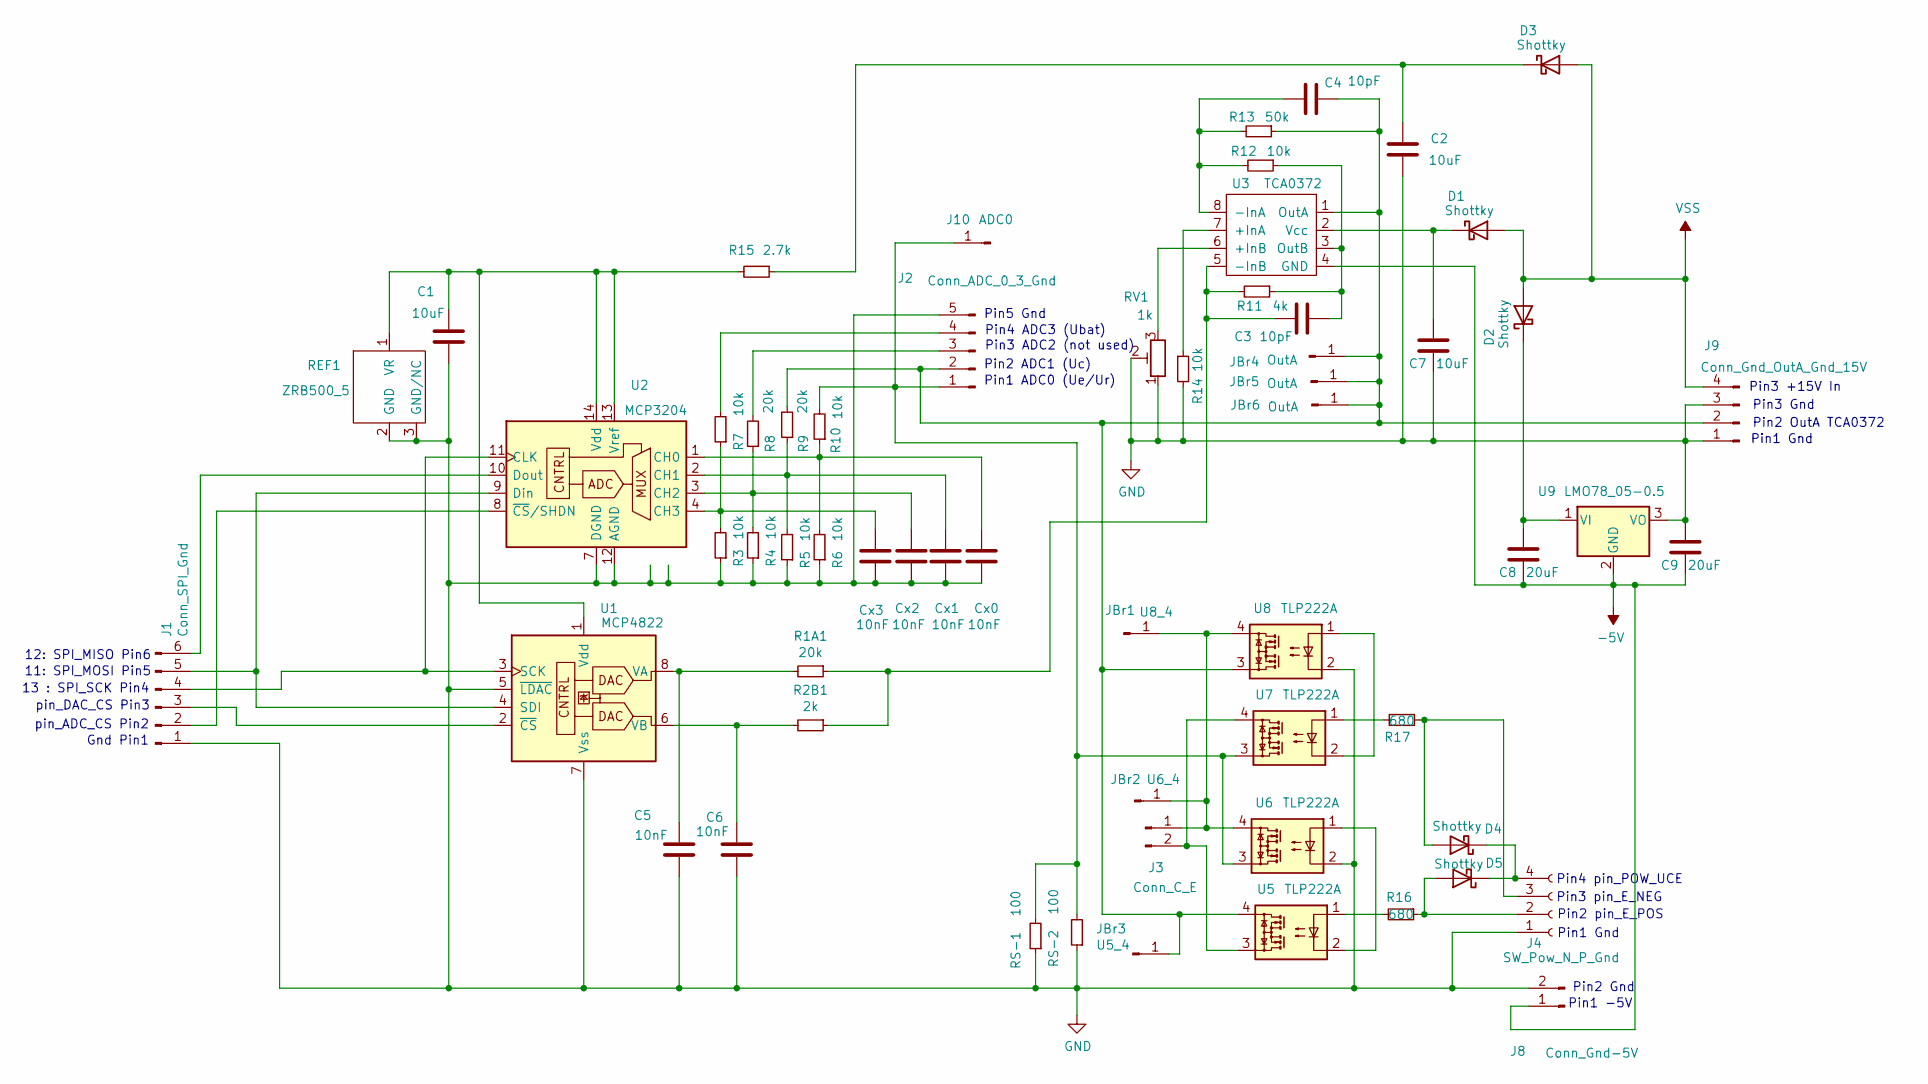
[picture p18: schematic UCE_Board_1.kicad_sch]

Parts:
C1: 10uF; C_1210_3225Metric_Pad1.33x2.70mm_HandSolder
C2: 10uF; C_1812_4532Metric_Pad1.57x3.40mm_HandSolder
C3: 10pF; C_Axial_L5.1mm_D3.1mm_P7.50mm_Horizontal
C4: 10pF; C_Axial_L3.8mm_D2.6mm_P7.50mm_Horizontal
C5, C6: 10nF; C_1206_3216Metric_Pad1.33x1.80mm_HandSolder
C7: 10uF; C_1206_3216Metric_Pad1.33x1.80mm_HandSolder
C8, C9: 20uF; C_1812_4532Metric_Pad1.57x3.40mm_HandSolder
Cx0, Cx1, Cx2, Cx3: 10nF; C_0805_2012Metric_Pad1.18x1.45mm_HandSolder
D1, D2, D3: Shottky; D_1206_3216Metric_Pad1.42x1.75mm_HandSolder
D4, D5: Shottky; D_0603_1608Metric_Pad1.05x0.95mm_HandSolder
J1: Conn_SPI_Gnd; PinHeader_1x06_P2.54mm_Horizontal
J2: Conn_ADC_0_3_Gnd; PinHeader_1x05_P2.54mm_Vertical
J3: Conn_C_E; PinHeader_1x02_P2.54mm_Horizontal
J4: SW_Pow_N_P_Gnd; PinHeader_1x04_P2.54mm_Horizontal
J8: Conn_Gnd-5V; PinHeader_1x02_P2.54mm_Vertical
J9: Conn_Gnd_OutA_Gnd_15V; PinHeader_1x04_P2.54mm_Horizontal
J10: ADC0; PinHeader_1x01_P2.54mm_Vertical
JBr1: U8_4; PinHeader_1x01_P2.54mm_Vertical
JBr2: U6_4; PinHeader_1x01_P2.54mm_Vertical
JBr3: U5_4; PinHeader_1x01_P2.54mm_Vertical
JBr4, JBr5, JBr6: OutA; PinHeader_1x01_P2.54mm_Vertical
R1A1, R8, R9: 20k; R_1206_3216Metric_Pad1.30x1.75mm_HandSolder
R2B1: 2k; R_1206_3216Metric_Pad1.30x1.75mm_HandSolder
R3, R4, R5, R6, R7, R10: 10k; R_1206_3216Metric_Pad1.30x1.75mm_HandSolder
R11: 4k; R_Axial_DIN0207_L6.3mm_D2.5mm_P10.16mm_Horizontal
R12: 10k; R_Axial_DIN0207_L6.3mm_D2.5mm_P10.16mm_Horizontal
R13: 50k; R_Axial_DIN0207_L6.3mm_D2.5mm_P10.16mm_Horizontal
R14: 10k; R_Axial_DIN0207_L6.3mm_D2.5mm_P15.24mm_Horizontal
R15: 2.7k; R_Axial_DIN0207_L6.3mm_D2.5mm_P10.16mm_Horizontal
R16, R17: 680; R_Axial_DIN0207_L6.3mm_D2.5mm_P10.16mm_Horizontal
REF1: ZRB500_5; SOT-23
RS-1, RS-2: 100; R_Axial_DIN0207_L6.3mm_D2.5mm_P10.16mm_Horizontal
RV1: 1k; Potentiometer_ACP_CA9-H2,5_Horizontal
U1: MCP4822; DIP-8_W7.62mm_LongPads
U2: MCP3204; DIP-14_W7.62mm
U3: TCA0372; DIP-8_W7.62mm_LongPads
U5, U6, U7, U8: TLP222A; DIP-4_W7.62mm
U9: LMO78_05-0.5; TO-220-3_Vertical

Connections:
-5V: C8.2, C9.2, J8.1, U3.4 (GND), U9.2 (GND)
GND: C1.2, C2.2, C5.1, C6.1, C7.2, C9.1, Cx0.1, Cx1.1, Cx2.1, Cx3.1, J1.1, J2.5, J4.1, J8.2, J9.1, J9.3, R3.1, R4.1, R5.1, R6.1, R14.2, REF1.2 (GND), REF1.3 (GND/NC), RS-1.1, RS-2.1, RV1.1, RV1.2, U1.5 (~LDAC), U1.7 (Vss), U2.5 (NC), U2.6 (NC), U2.7 (DGND), U2.12 (AGND), U6.2, U8.2, U9.3 (VO)
unnamed: C1.1, R15.2, REF1.1 (VR), U1.1 (Vdd), U2.13 (Vref), U2.14 (Vdd)
unnamed: C2.1, D3.1 (K), R15.1
unnamed: C3.1, R11.1, R12.1, U3.3 (OutB)
unnamed: C3.2, R1A1.1, R2B1.1, R11.2, U3.5 (-InB)
unnamed: C4.1, J2.2, J9.2, JBr3.1, JBr4.1, JBr5.1, JBr6.1, R9.2, R13.1, U3.1 (OutA), U5.4, U8.3
unnamed: C4.2, R12.2, R13.2, U3.8 (-InA)
unnamed: C5.2, R1A1.2, U1.8 (VA)
unnamed: C6.2, R2B1.2, U1.6 (VB)
unnamed: C7.1, D1.1 (K), U3.2 (Vcc)
unnamed: C8.1, D2.1 (K), U9.1 (VI)
unnamed: Cx0.2, R6.2, R10.1, U2.1 (CH0)
unnamed: Cx1.2, R5.2, R9.1, U2.2 (CH1)
unnamed: Cx2.2, R4.2, R8.1, U2.3 (CH2)
unnamed: Cx3.2, R3.2, R7.1, U2.4 (CH3)
unnamed: D4.1 (K), D5.1 (K), J4.4
unnamed: D4.2 (A), J4.3, R17.1
unnamed: D5.2 (A), J4.2, R16.1
unnamed: J1.2, U2.8 (~CS/SHDN)
unnamed: J1.3, U1.2 (~CS)
unnamed: J1.4, U1.3 (SCK), U2.11 (CLK)
unnamed: J1.5, U1.4 (SDI), U2.9 (Din)
unnamed: J1.6, U2.10 (Dout)
unnamed: J2.3, R8.2
unnamed: J2.4, R7.2
unnamed: J3.1, JBr1.1, JBr2.1, U6.4, U8.4
unnamed: J3.2, U5.3, U7.4
unnamed: J2.1, J10.1, R10.2, RS-1.2, RS-2.2, U6.3, U7.3
unnamed: R14.1, U3.7 (+InA)
unnamed: R16.2, U5.1
unnamed: R17.2, U7.1
unnamed: RV1.3, U3.6 (+InB)
unnamed: U5.2, U6.1
unnamed: U7.2, U8.1
VSS: D1.2 (A), D2.2 (A), D3.2 (A), J9.4

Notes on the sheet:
pin_ADC_CS Pin2
Pin1 Gnd
Pin5 Gnd
Gnd Pin1
Pin3 pin_E_NEG
Pin2 OutA TCA0372
Pin4 pin_POW_UCE
12: SPI_MISO Pin6
Pin2 ADC1 (Uc)
pin_DAC_CS Pin3
Pin2 pin_E_POS
Pin3 ADC2 (not used)
Pin2 Gnd
Pin1 ADC0 (Ue/Ur)
Pin3 +15V In
Pin1 -5V
Pin3 Gnd
11: SPI_MOSI Pin5
Pin4 ADC3 (Ubat)
13 : SPI_SCK Pin4

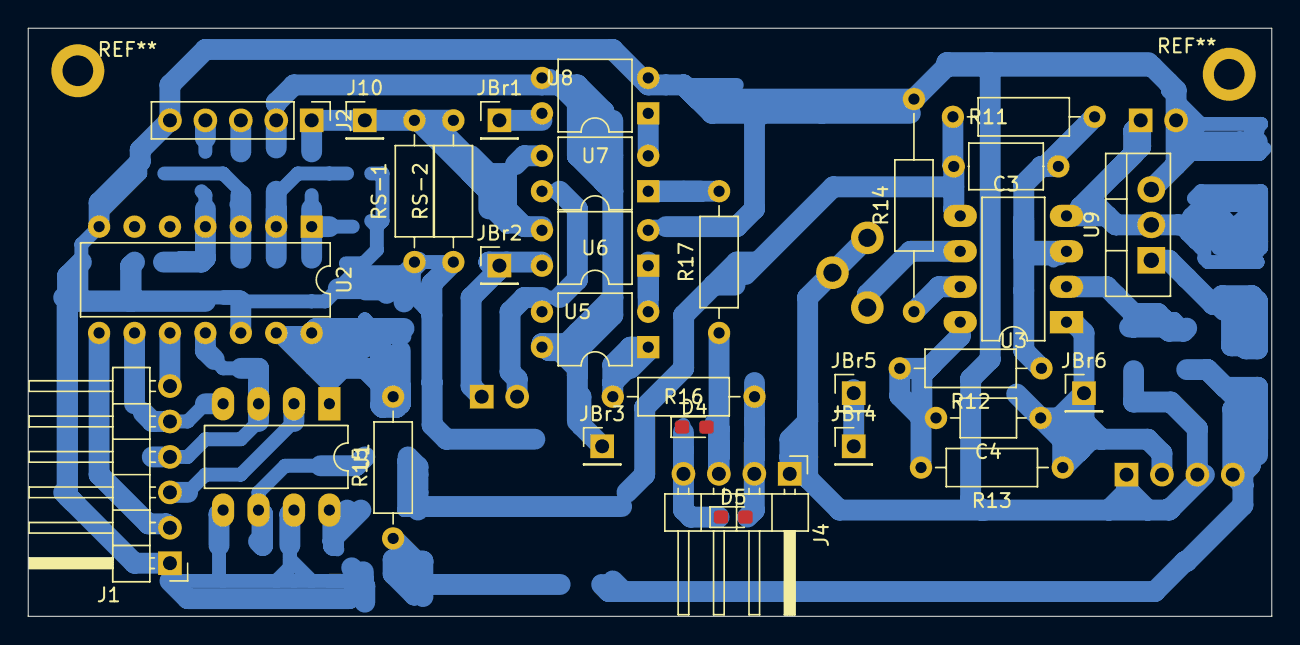
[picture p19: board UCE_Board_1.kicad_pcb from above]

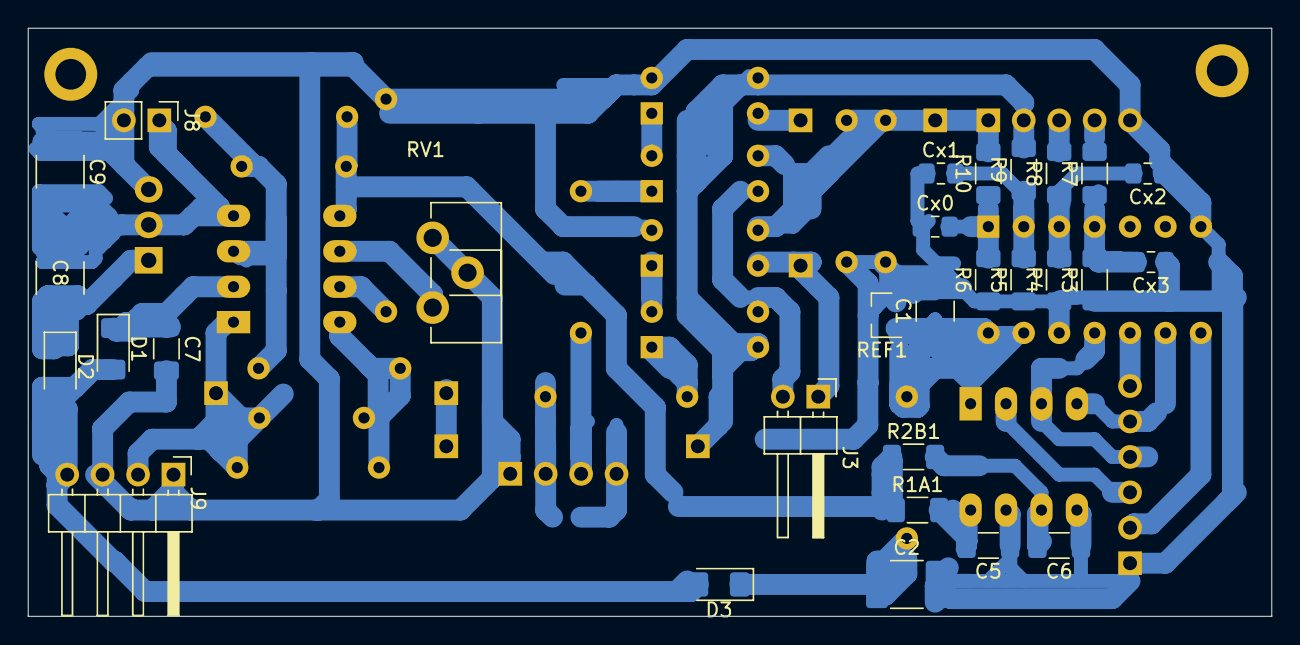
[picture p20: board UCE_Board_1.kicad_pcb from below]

Board: 2 copper layers, 89.2 x 42.2 mm, 60 parts (29 on the bottom side), 36 nets.

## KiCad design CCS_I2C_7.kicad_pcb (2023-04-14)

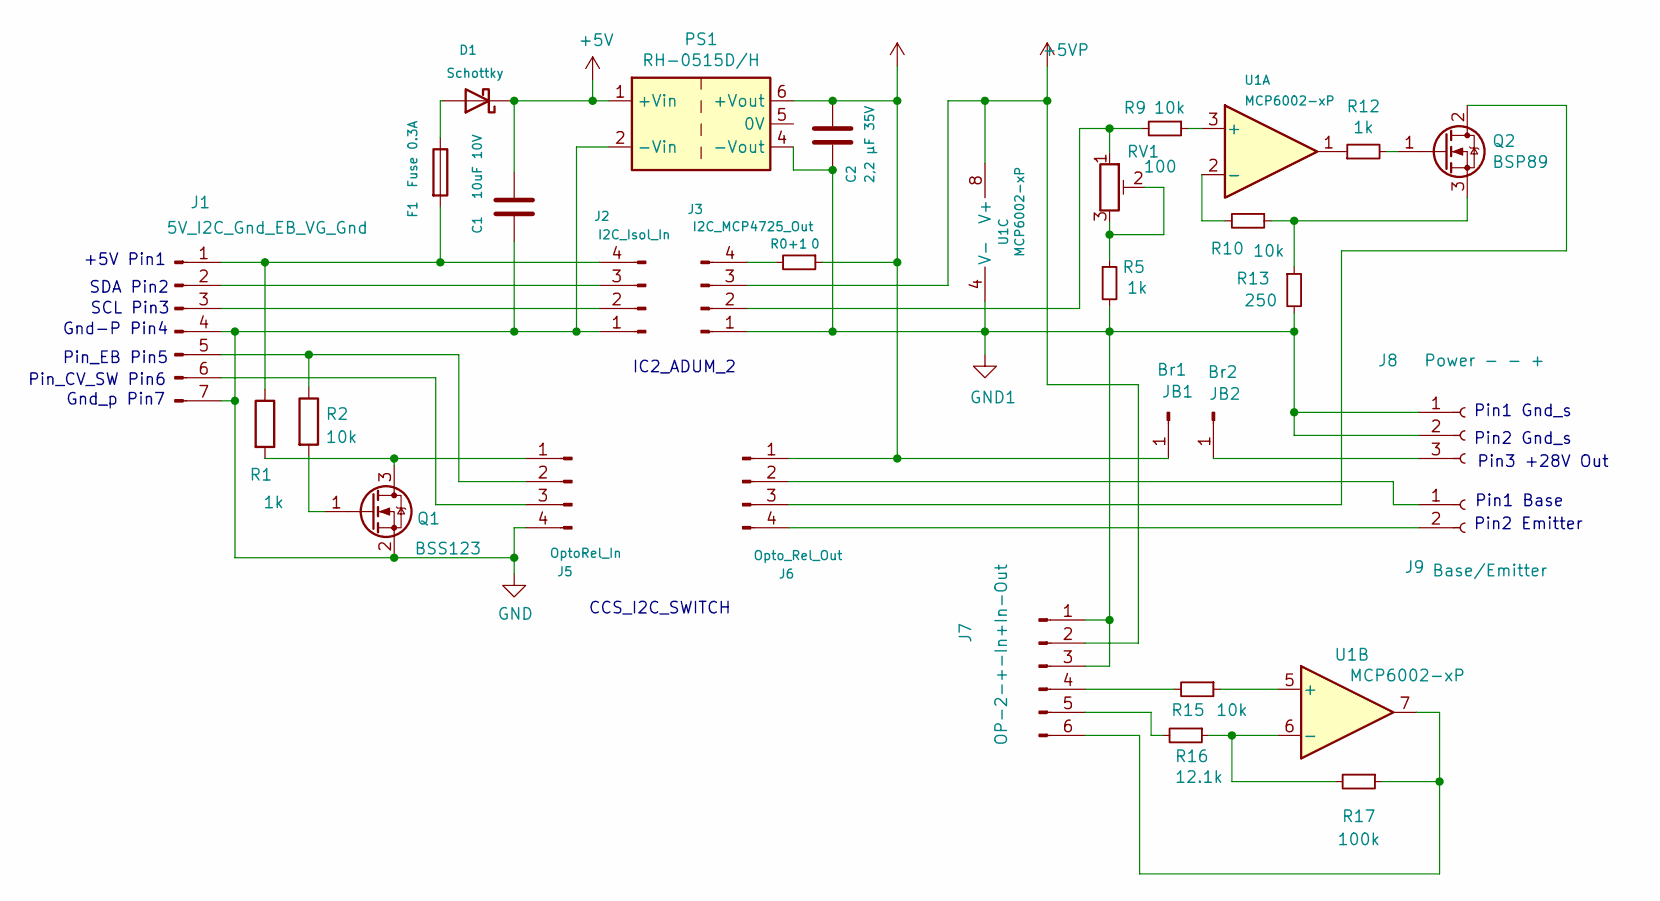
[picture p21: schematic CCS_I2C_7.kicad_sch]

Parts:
C1: 10uF 10V; C_1812_4532Metric_Pad1.57x3.40mm_HandSolder
C2: 2,2 µF 35V; C_1812_4532Metric_Pad1.57x3.40mm_HandSolder
D1: Schottky; D_1206_3216Metric_Pad1.42x1.75mm_HandSolder
F1: Fuse 0.3A; Fuse_1206_3216Metric_Pad1.42x1.75mm_HandSolder
J1: 5V_I2C_Gnd_EB_VG_Gnd; PinHeader_1x07_P2.54mm_Horizontal
J2: I2C_Isol_In; PinSocket_1x04_P2.54mm_Vertical
J3: I2C_MCP4725_Out; PinSocket_1x04_P2.54mm_Vertical
J5: OptoRel_In; PinSocket_1x04_P2.54mm_Vertical
J6: Opto_Rel_Out; PinSocket_1x04_P2.54mm_Vertical
J7: OP-2-+-In+In-Out; PinHeader_1x06_P2.54mm_Horizontal
J8: Power - - +; PinHeader_1x03_P2.54mm_Horizontal
J9: Base/Emitter; PinHeader_1x02_P2.54mm_Horizontal
JB1: Br1; PinHeader_1x01_P2.54mm_Vertical
JB2: Br2; PinHeader_1x01_P2.54mm_Vertical
PS1: RH-0515D/H; Converter_DCDC_XP_POWER-IHxxxxSH_THT
Q1: BSS123; SOT-23
Q2: BSP89; SOT-223-3_TabPin2
R0+1: 0; R_Axial_DIN0309_L9.0mm_D3.2mm_P12.70mm_Horizontal
R1: 1k; R_1206_3216Metric_Pad1.30x1.75mm_HandSolder
R2: 10k; R_1206_3216Metric_Pad1.30x1.75mm_HandSolder
R5, R12: 1k; R_Axial_DIN0207_L6.3mm_D2.5mm_P10.16mm_Horizontal
R9, R10, R15: 10k; R_Axial_DIN0207_L6.3mm_D2.5mm_P10.16mm_Horizontal
R13: 250; R_Axial_DIN0207_L6.3mm_D2.5mm_P10.16mm_Horizontal
R16: 12.1k; R_Axial_DIN0207_L6.3mm_D2.5mm_P10.16mm_Horizontal
R17: 100k; R_Axial_DIN0207_L6.3mm_D2.5mm_P10.16mm_Horizontal
RV1: 100; Potentiometer_ACP_CA6-H2,5_Horizontal
U1: MCP6002-xP; DIP-8_W7.62mm_LongPads

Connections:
+5V: C1.1, D1.1 (K), PS1.1 (+Vin)
+5VP: J3.3, J7.2, U1.8 (V+)
+28V: C2.1, J6.1, JB1.1, PS1.6 (+Vout), R0+1.1
GND: C1.2, J1.4, J1.7, J2.1, J5.4, PS1.2 (-Vin), Q1.2 (S)
GND1: C2.2, J3.1, J7.1, J7.3, J8.1, J8.2, PS1.4 (-Vout), R5.2, R13.2, U1.4 (V-)
unnamed: D1.2 (A), F1.1
unnamed: F1.2, J1.1, J2.4, R1.1
unnamed: J1.2, J2.3
unnamed: J1.3, J2.2
unnamed: J1.5, J5.2, R2.1
unnamed: J1.6, J5.3
unnamed: J3.2, R9.2, RV1.1
unnamed: J3.4, R0+1.2
unnamed: J5.1, Q1.3 (D), R1.2
unnamed: J6.2, J9.1
unnamed: J6.3, Q2.2 (D)
unnamed: J6.4, J9.2
unnamed: J7.4, R15.2
unnamed: J7.5, R16.2
unnamed: J7.6, R17.1, U1.7
unnamed: J8.3, JB2.1
unnamed: Q1.1 (G), R2.2
unnamed: Q2.1 (G), R12.2
unnamed: Q2.3 (S), R10.1, R13.1
unnamed: R5.1, RV1.2, RV1.3
unnamed: R9.1, U1.3 (+)
unnamed: R10.2, U1.2 (-)
unnamed: R12.1, U1.1
unnamed: R15.1, U1.5 (+)
unnamed: R16.1, R17.2, U1.6 (-)

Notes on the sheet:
Pin_EB Pin5
IC2_ADUM_2
+5V Pin1
Gnd-P Pin4
SDA Pin2
Pin2 Gnd_s
Pin3 +28V Out
SCL Pin3
Pin2 Emitter
Gnd_p Pin7
Pin1 Gnd_s
Pin1 Base
CCS_I2C_SWITCH
Pin_CV_SW Pin6

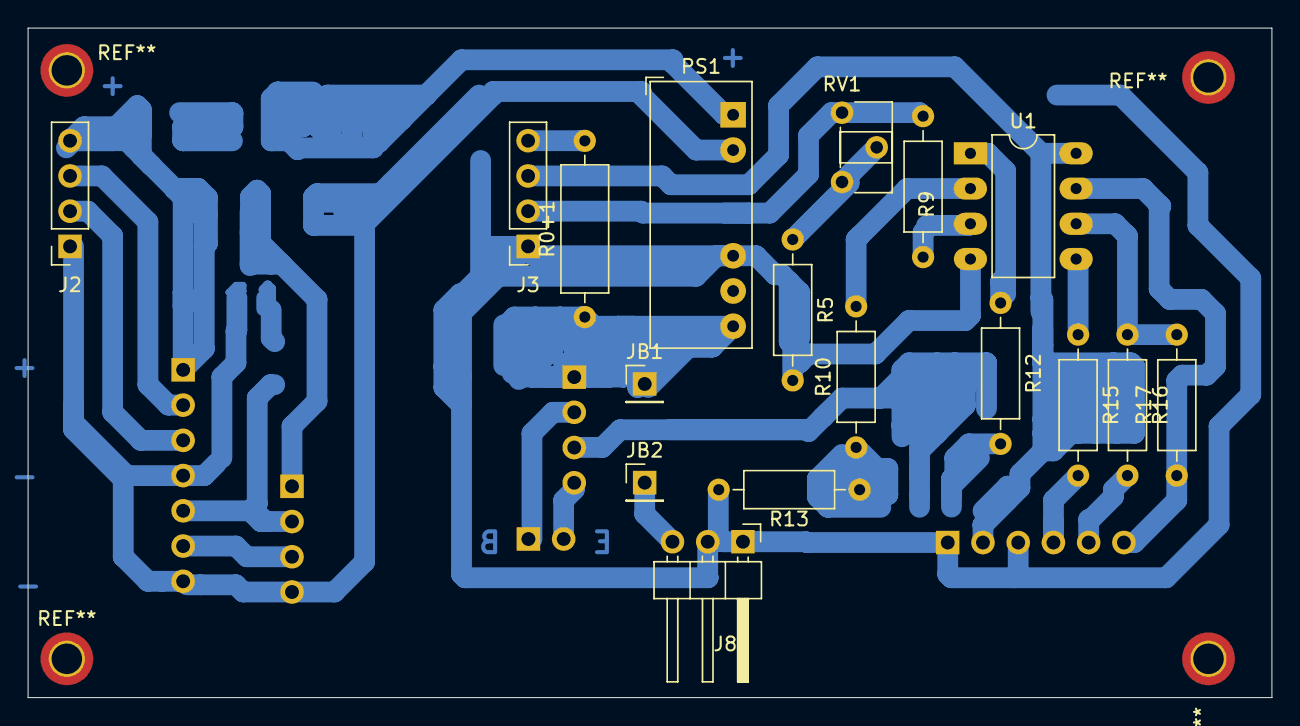
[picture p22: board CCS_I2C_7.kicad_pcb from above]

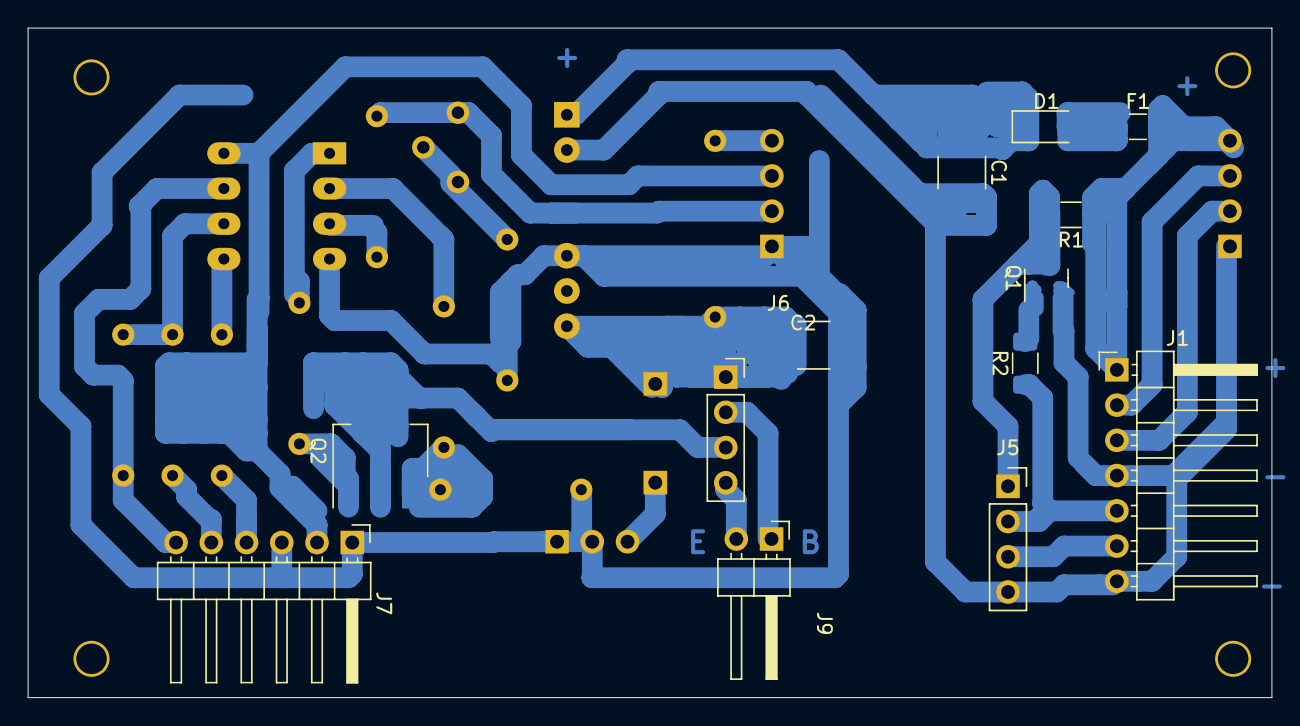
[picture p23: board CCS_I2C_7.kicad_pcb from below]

Board: 2 copper layers, 89.7 x 48.3 mm, 30 parts (13 on the bottom side), 30 nets.
